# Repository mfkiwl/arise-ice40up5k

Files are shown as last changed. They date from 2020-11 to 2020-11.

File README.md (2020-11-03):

# arise
Low cost development board based on UP5K.
This is an open-source platform based on a low cost FPGA chip from Lattice, aiming to be used in a wide range of signal processing and control applications, both for education and the industry.
This development supports the Open Source toolchain by [Clifford Wolf](http://www.clifford.at/icestorm/).

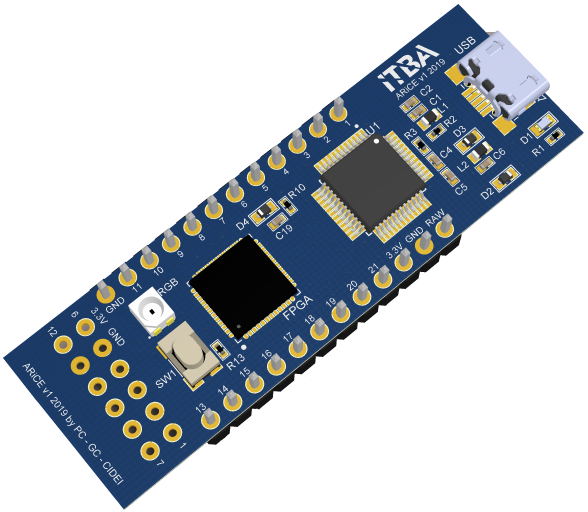
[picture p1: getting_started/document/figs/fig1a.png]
ARiCE


## Getting Started

- If you are starting from scratch, read our [Getting Started Guide](getting_started/document/gs_apio.pdf) to set up the software to program the FPGA board. Further documentation can be found in the ["getting_started" folder](getting_started/document).
- Example code for the recommended software can be found in the ["examples" folder](getting_started/example).
- You can download the Schematics and board files by going to the ["altium" folder](Altium) in this repository or by visiting our project in [Circuit Maker](https://workspace.circuitmaker.com/Projects/Details/Gonzalo-Castelli/FPGA-ITBA), a free PCB design software for the Open Source Hardware community.
- KiCAD version in progress

## Authors
This project was concieved at Instituto Tecnológico de Buenos Aires, in Argentina, by the Industrial Electronic Research and Development Center members:
* **Pablo Cossutta** - *Initial work* - [GitHub page](https://github.com/pcossutta)
* **Gonzalo Castelli** - *Initial work* - [GitHub page](https://github.com/gonzalocastelli)

## License

This project is licensed under a Creative Commons Attribution Share-Alike license, meaning that you are free to use and adapt it for your own needs without asking for permission or paying a fee, even for commercial purposes, as long as you give appropriate credit and release the design under the same license. See the [LICENSE.md](LICENSE.md) file for details, or visit the [Creative Commons Website](https://creativecommons.org/licenses/by-sa/3.0/).

## Acknowledgments

* Circuit was inspired by the official manuals and toolchain of the [iCE40 UltraPlus Breakout Board](http://www.latticesemi.com/en/Products/DevelopmentBoardsAndKits/iCE40UltraPlusBreakoutBoard.aspx) from Lattice, and the documentation of the iCE40UP5K FPGA chip.

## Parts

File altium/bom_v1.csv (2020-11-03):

Designator | Part Number | Qty | Link
C1, C7, C11, C13, C15, C17, C20, C22 | 302010040 | 8 | CC0402KRX5R6BB105 | 1uF 0402
C2, C3, C4, C5, C6, C10, C12, C14, C16, C18, C19, C21, C23 | 302010024 | 13 | CC0402KRX7R8BB104 | 0.1 uF 0402
C8, C9 | 302010139 | 6 | CC0603KRX7R8BB105 | 1uF 0603
R2 | 301010039 | 1 | RC0402JR-072K2L
D1 | 304090045 | 1 | 19-217-BHC-ZL1M2RY-3T
D2, D3, D4 | CDBU0520 | 3
FPGA | ICE40UP5K-SG48I | 1 | https://www.digikey.com/product-detail/en/lattice-semiconductor-corporation/ICE40UP5K-SG48I/220-2212-1-ND/9563352
L1 | HI0603P600R-10 | 1
L2, L3, L4 | BLM18HE601SN1D | 3
MEM | W25Q32JVSSIQ | 1
OSC1 | SIT8924BE-72-XXE-12.000000E | 1
R1 | 301010006 | 1
R3, R4, R5, R6, R7, R13 | 301010047 | 6
R8, R9, R10, R11, R12 | AC0402JR-071RL | 5
RGB | CLMVC-FKA-CL1D1L71BB7C3C3 | 1
SW1 | 311020518 | 1
U1 | FT232HL-REEL | 1
U2 | TLV1117LV33DCYR | 1
U3 | LP5907MFX-1.2/NOPB | 1
USB | 320010000 | 1

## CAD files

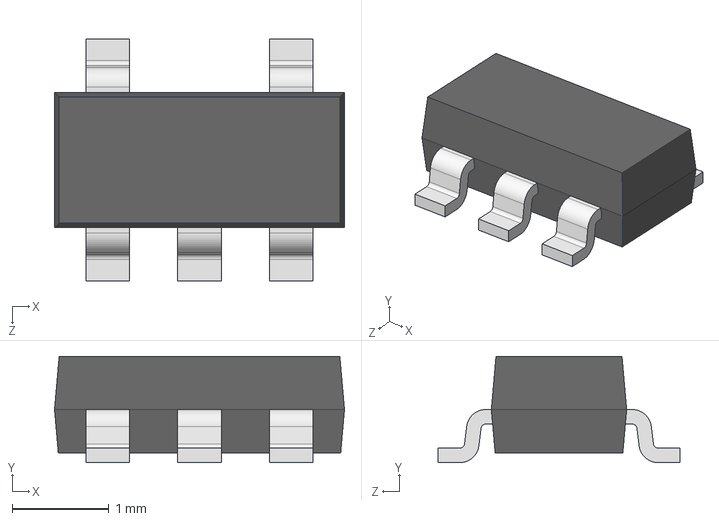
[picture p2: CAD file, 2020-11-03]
altium/3D models/SW3DPS-SOT-23-5-DEFAULT.STEP
3.00 x 1.10 x 2.50 mm

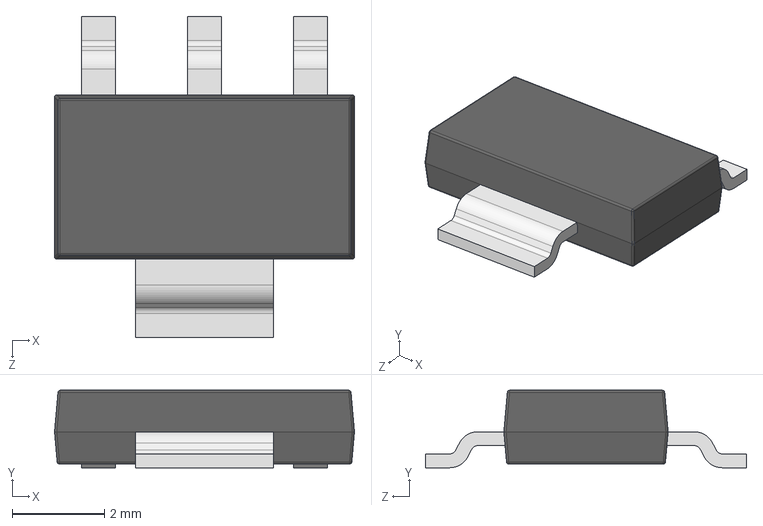
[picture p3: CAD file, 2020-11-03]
altium/My Libraries/Burr-Brown/SW3DPS-SOT-223-DEFAULT.STEP
6.50 x 1.68 x 6.96 mm

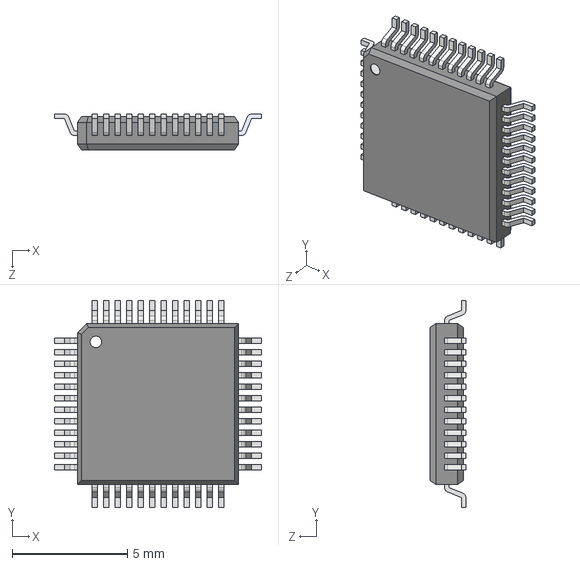
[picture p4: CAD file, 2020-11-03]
altium/My Libraries/Imported FT232HL-REEL.lia/SW3dPS-Quad50M48.STEP
9.00 x 9.00 x 1.56 mm

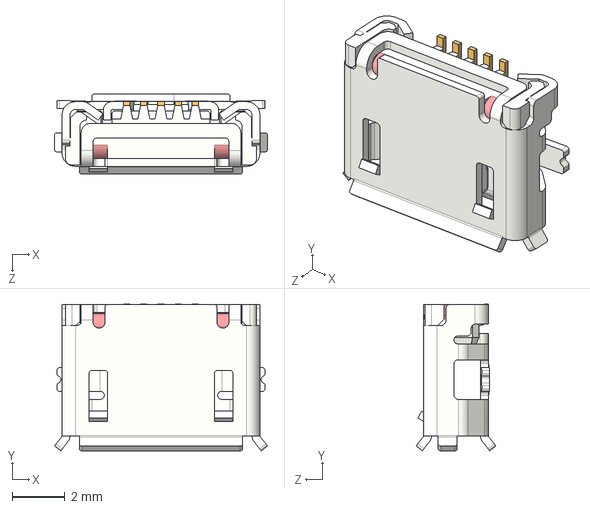
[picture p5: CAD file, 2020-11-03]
altium/My Libraries/Seeed/Connectors/User Library-10104110.STEP
8.08 x 5.56 x 3.03 mm

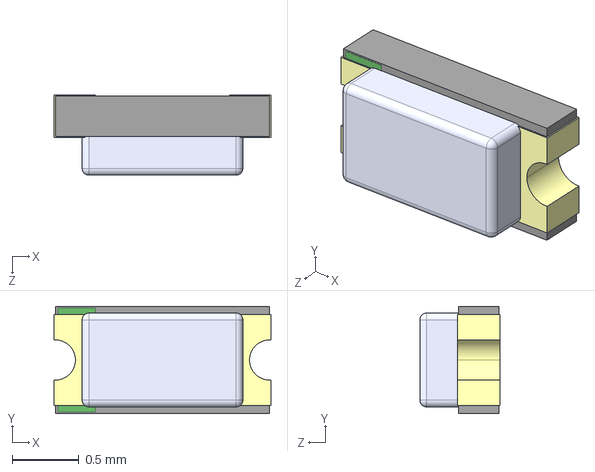
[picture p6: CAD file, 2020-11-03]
altium/My Libraries/Seeed/LED/alsrobot-LED0603(G).STEP
1.62 x 0.8 x 0.6 mm

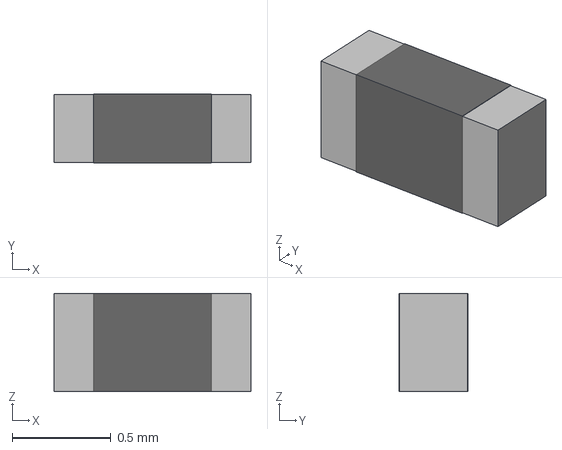
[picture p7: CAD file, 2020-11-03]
altium/My Libraries/Seeed/Resistors/rnd_1550402wgf470ktce.stp
1.00 x 0.35 x 0.5 mm

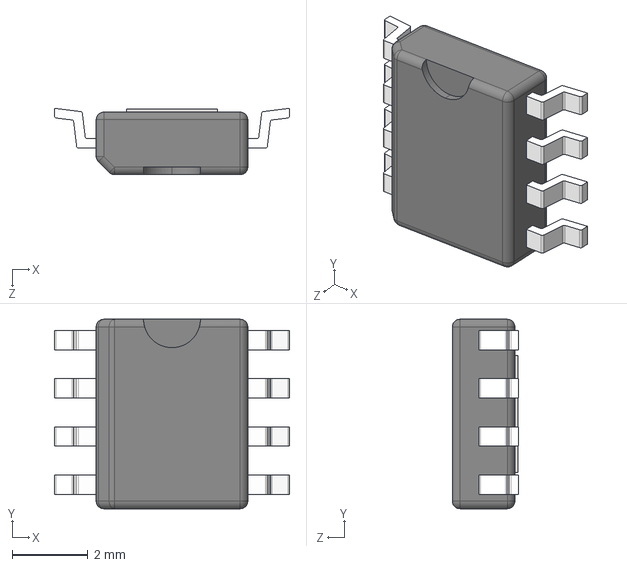
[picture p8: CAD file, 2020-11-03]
altium/3D models/User Library-HSOP8-1.STEP
6.20 x 5.00 x 1.75 mm
User Library-HSOP8-1_SO8
User Library-HSOP8-1_Extruded

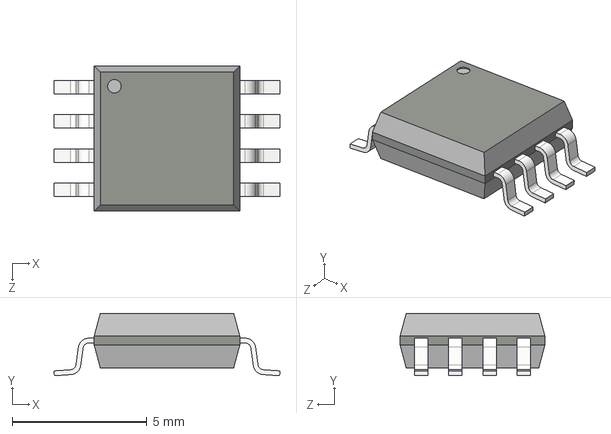
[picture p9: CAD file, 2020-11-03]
altium/3D models/SW3dPS-SOIC8_(ATTINY12).STEP
8.39 x 2.32 x 5.38 mm

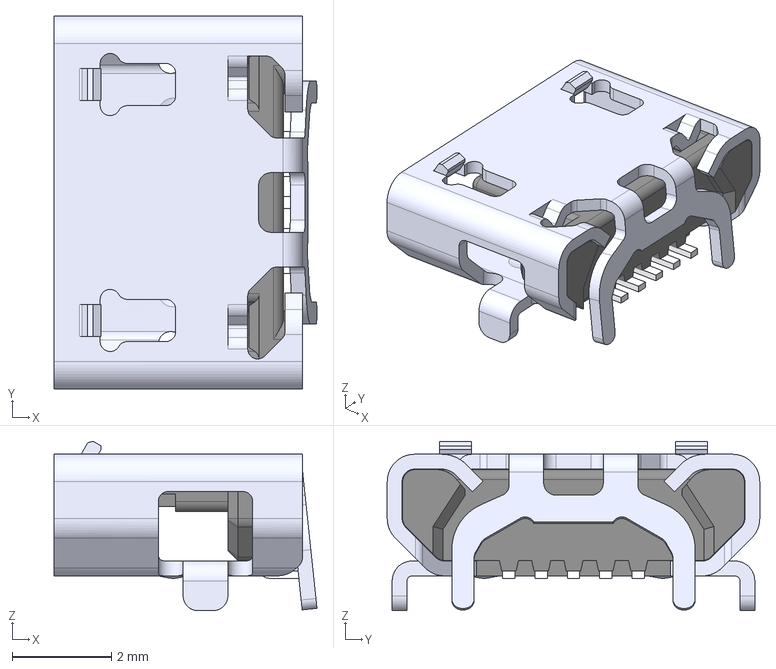
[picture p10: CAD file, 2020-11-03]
altium/3D models/uj2-mibh2-4-smt.stp
5.29 x 7.50 x 3.41 mm

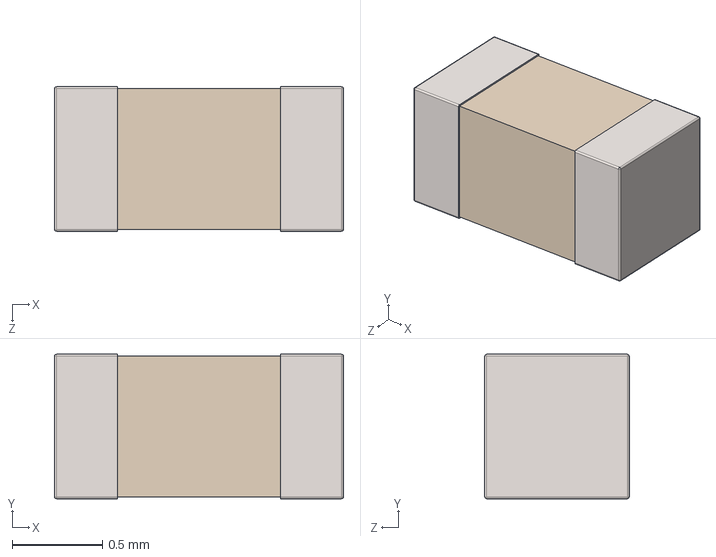
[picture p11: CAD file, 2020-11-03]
altium/3D models/User Library-SMD CAPACITOR0603.STEP
1.60 x 0.8 x 0.8 mm

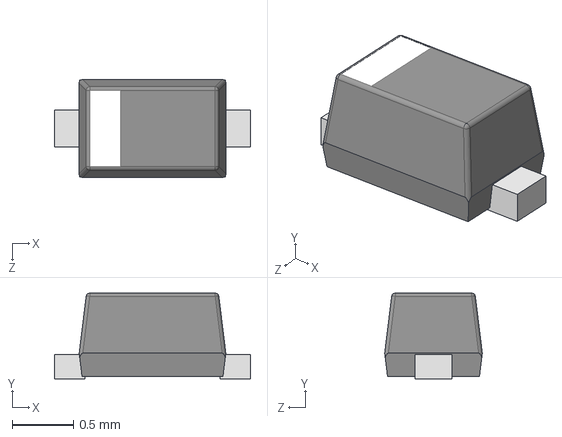
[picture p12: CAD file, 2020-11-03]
altium/3D models/User Library-SOD-523F.STEP
1.60 x 0.7 x 0.798 mm

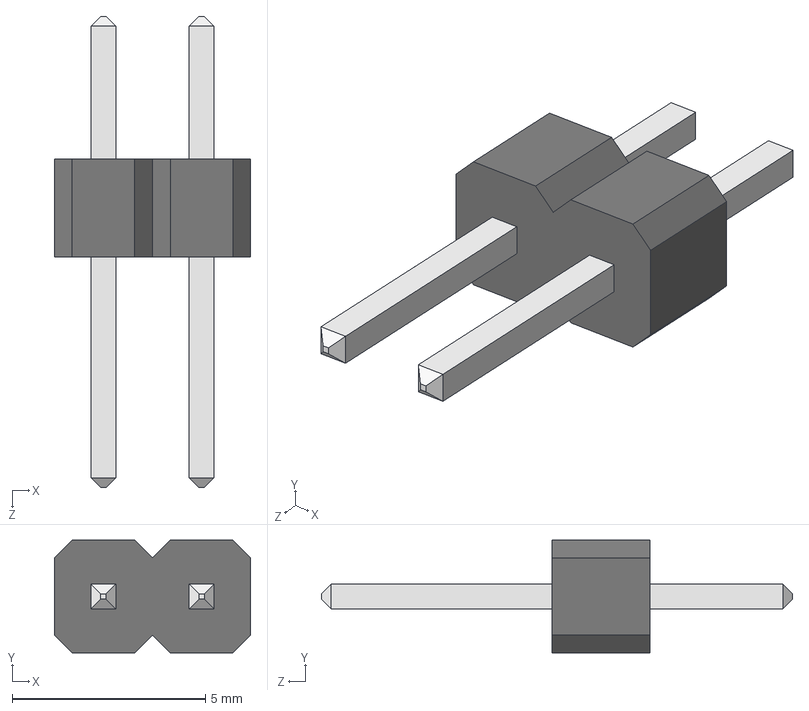
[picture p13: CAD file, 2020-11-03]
altium/3D models/User Library-Pin Header Strip.STEP
5.08 x 2.92 x 12.2 mm

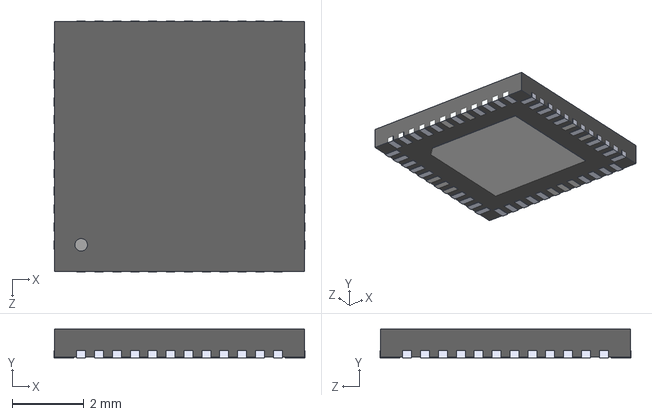
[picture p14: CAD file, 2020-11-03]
altium/3D models/ALSRobot-QFN48 7x7.STEP
7.02 x 0.8 x 7.02 mm

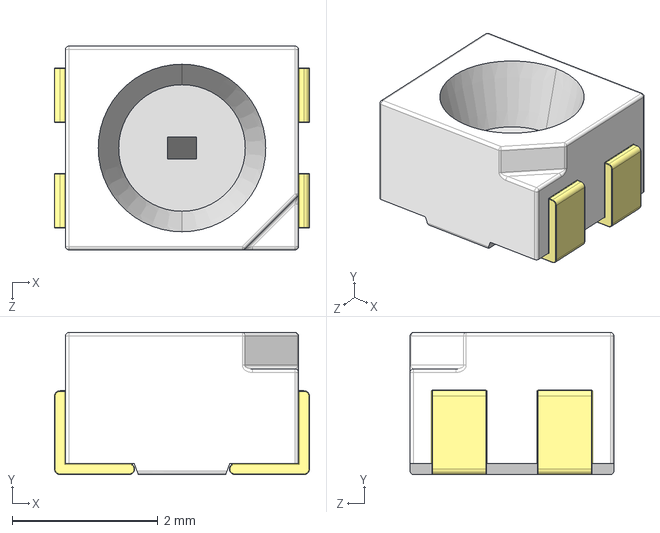
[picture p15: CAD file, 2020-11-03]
altium/3D models/SW3dPS-Osram_Led_PLCC4-1.STEP
3.50 x 1.95 x 2.80 mm

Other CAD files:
altium/3D models/User Library-LS8.STEP
altium/3D models/45631.stp
altium/3D models/User Library-Oscillator2520-4pol.STEP
altium/3D models/User Library-SMD CAPACITOR0402.STEP

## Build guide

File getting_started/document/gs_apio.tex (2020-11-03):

% !TEX encoding = UTF-8 Unicode
\documentclass[11pt, a4paper, oneside]{article}
\usepackage[onehalfspacing]{setspace}		% One half spacing
\usepackage{hyperref}					% Hyperlinks on pdf (Should be called before Geometry)
\usepackage[a4paper, 					% Page Layout
                     %showframe,				% This shows the frame
                     twoside, includehead,
                     footskip=7mm, headsep=6mm, headheight=4.8mm,
                     marginparsep=2mm, marginparwidth=22mm,
                     top=25mm, bottom=25mm, inner=30mm, outer=25mm]{geometry}
\usepackage{sansmathfonts}				% Sans Serif equations
\usepackage[T1]{fontenc}					% Output font encoding for international characters
\usepackage[utf8]{inputenc}				% Encoding of files: utf8
\renewcommand*\familydefault{\sfdefault} 		% Sans Serif as default font
\usepackage[table]{xcolor}
\usepackage{graphicx}
\usepackage{pdfpages}
\usepackage{array}
\hypersetup{
    colorlinks=true,
    linkcolor=blue,
    filecolor=magenta,      
    urlcolor=blue,
}
\urlstyle{same}
\usepackage{tikz}
\RequirePackage{caption} 				% Caption customization
\captionsetup{justification=centerlast,font=small,labelfont=sc,margin=1cm}

\usepackage{array}
\newcommand{\PreserveBackslash}[1]{\let\temp=\\#1\let\\=\temp}
\newcolumntype{C}[1]{>{\PreserveBackslash\centering}p{#1}}
\newcolumntype{R}[1]{>{\PreserveBackslash\raggedleft}p{#1}}
\newcolumntype{L}[1]{>{\PreserveBackslash\raggedright}p{#1}}

\begin{document}
\begin{titlepage}
	\onehalfspacing
	\enlargethispage{0.65\baselineskip}
	\begin{tikzpicture}[remember picture, overlay]
		\coordinate (top_right) at 
		    ([xshift=-2.5cm, yshift=-2.5cm]current page.north east);
		\coordinate (top_left) at 
		    ([xshift=2.3cm, yshift=-1.8cm]current page.north west);
		\coordinate (bottom_right) at 
		    ([xshift=-1.8cm, yshift=1.8cm]current page.south east);
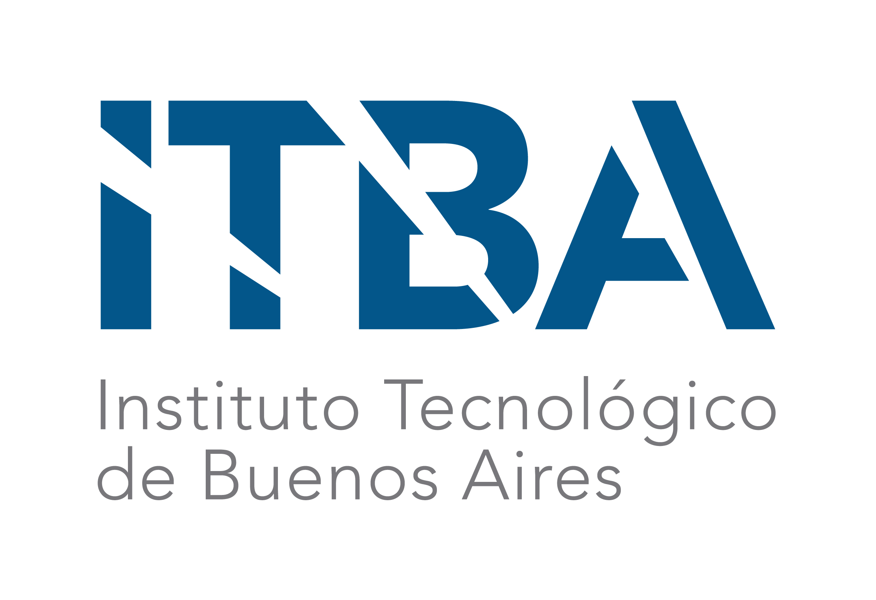
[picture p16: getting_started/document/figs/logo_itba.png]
		\node[inner sep=0, anchor=north east] at (top_right) {\href{http://www.itba.edu.ar}{}};
		\draw[double, line width = 0.5pt] (top_left) rectangle (bottom_right);
	\end{tikzpicture}
	\par
	\vspace{-0.8cm}
	\noindent \textbf{CENTRO DE INVESTIGACIÓN Y DESARROLLO EN}\par
	\noindent \textbf{ELECTRONICA INDUSTRIAL (CIDEI)}\par
	\vspace{3cm}
	\begin{center}
		{\Huge \textbf{ARiCE Plattform}\par}
		{\huge \textbf{Getting Started Apio}\par}
	\end{center}
	\vspace{1cm}
	\begin{center}
		
	\end{center}
	\vfill
	\noindent \textbf{AUTHORS:} Dr. Ing. Pablo \textsc{Cossutta} - Ing. Gonzalo \textsc{Castelli} - Rodrigo \textsc{Devesa} \par
	\vfill
	\begin{center}
		\textbf{CIUDAD AUTÓNOMA DE BUENOS AIRES}\\
		\textbf{2018-2019}\par
	\end{center}
\end{titlepage}

\tableofcontents
\newpage

\section{Introduction}
This project is an open-source platform,shown on Fig. \ref{fig1},  based on a low cost and low consumption FPGA chip from \href{http://www.latticesemi.com}{Lattice Semiconductor}, aiming to be used in a wide range of signal processing and control applications, both for education and the industry.
%
\begin{figure}[h!]
	\centering
	\\
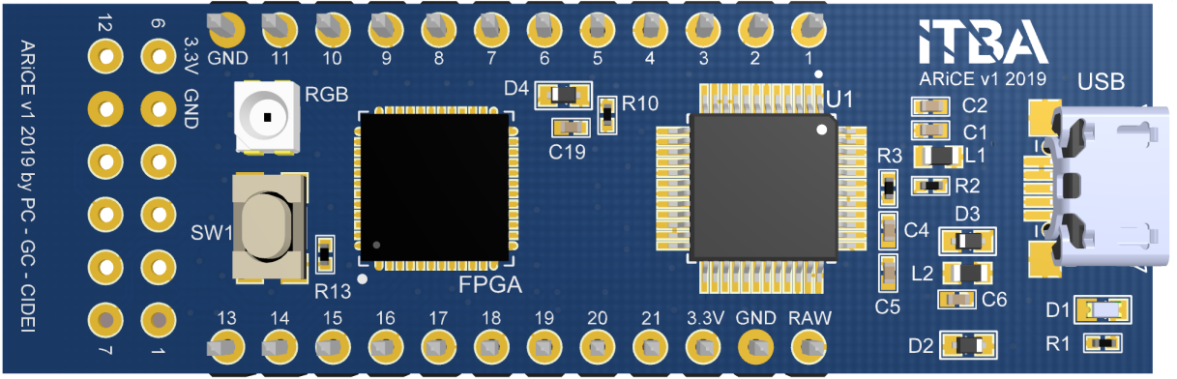
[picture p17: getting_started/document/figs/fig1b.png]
	%
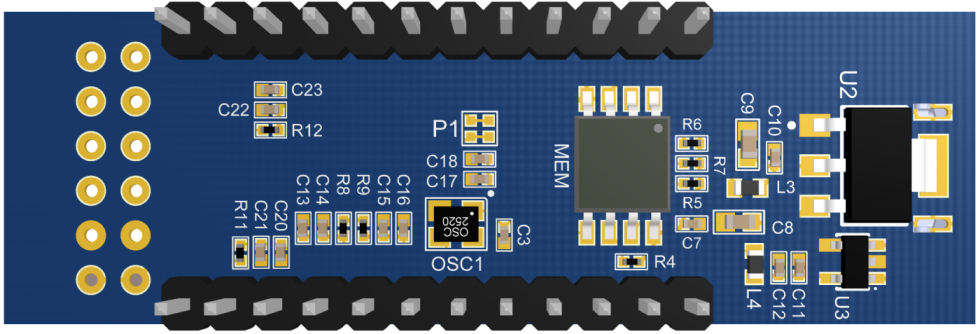
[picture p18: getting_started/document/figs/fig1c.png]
	
	\caption{Board's view}
	\label{fig1}
\end{figure}

%\subsection{Project file sources}
%The following list shows the different file sources for this project:
%\begin{itemize}
%	\item Getting Started Guide and Documentation: \href{https://github.com/pcossutta/Lattice-FPGA/tree/master/Documents/Manuals}{GitHub manuals}
%	\item PCB and Schematics: \href{https://workspace.circuitmaker.com/Projects/Details/Gonzalo-Castelli/FPGA-ITBA}{Circuit Maker} and \href{https://github.com/pcossutta/Lattice-FPGA/tree/master/Altium}{GitHub Altium Project Files}
%	\item \href{https://github.com/pcossutta/Lattice-FPGA/tree/master/Examples/LedExample}{Example code} for the Lattice Radiant software.
%\end{itemize}

\section{Getting started}
Without no previous knowledge, three main steps are necessary to use the board if you are starting from scratch. The first is to download and install the software, the second is to create a new project and include the code files needed and finally load the program to the onboard memory using a USB cable.

\subsection{Downloading the software}
Before using the board, it is necessary to set up the software to program the Lattice iCE40-UP5K FPGA chip. In this tutorial we will be utilizing the  \href{https://apiodoc.readthedocs.io/en/stable/index.html}{Apio Open Source Ecosystem for FPGAs}, which allows to verify the code and program the FPGA through a USB port.\href{https://apiodoc.readthedocs.io/en/stable/index.html}{Python 3.7+} should be previously installed in order to install Apio.

During Python installation, make sure to select "\textbf{Customize Installation}". Then, on the optional features screen, select to install pip, as shown in  Fig. \ref{fig2}, as we will be using it to download the Apio packages.
\ref{fig2}.

\begin{figure}[h!]
    \centering
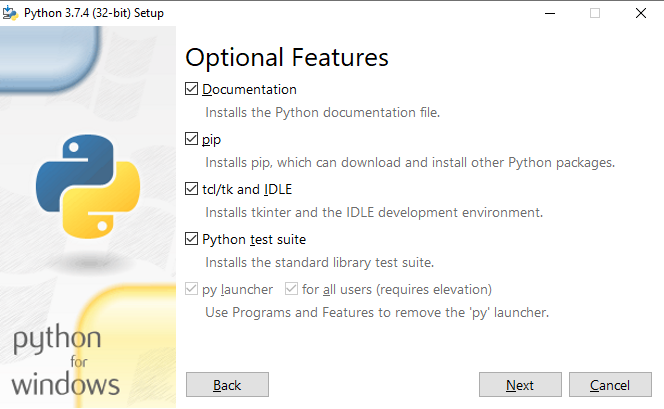
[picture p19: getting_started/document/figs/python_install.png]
    
    \caption{Setting up the Python installation}
    \label{fig2}
\end{figure}

Once Python is successfully installed along with Pip, you can install Apio. On Windows, open your command line console and type:
\begin{center}
	\texttt{pip install -U apio}
\end{center}
When it's finished, you will need to install Apio's packages. Use the following command:
\begin{center}
	\texttt{apio install -{}-all}
\end{center}
This installation might take a few minutes.

\subsection{Creating a new project}
After having installed the software, the next step is to create a new folder for the project and start writing the code. An example code that uses the onboard RGB LED is available for download at the GitHub repository of this project. After downloading the files, place them in an easily accessible folder from where we will run the code.

Use the \texttt{cd} command followed by the path to your project's folder to change directory to that folder. For example, if your project is on a folder called "fpga\_project" in your Desktop, then use:
\begin{center}
	\texttt{cd Desktop/fpga\_project}
\end{center}

Once in the right folder, you need to generate the right .init configuration file for this board, as Apio supports multiple different FPGA platforms. To do this, use the command:

\begin{center}
	\texttt{apio init -{}-board upduino2}
\end{center}

Now, to make sure the project is set up correctly, you could use the command:
\begin{center}
	\texttt{apio build}
\end{center}
The folder should contain at least 3 files, one .v file with the program's code itself, one .pcf file with pinout information for the program, and the .init file we just created. If the build process is successful, you can move on to programming the FPGA board.
 
\subsection{Programming the board}
Now that the project is fully set up, we can load the program into our board to run it.
Connect the FPGA board to the PC using the USB cable, wait a few seconds for Windows to configure the drivers, then use the following command to program the board:
\begin{center}
	\texttt{apio upload}
\end{center}
The process will take a few seconds, and if everything went right, the FPGA board should start running the program and its onboard LED should start flashing in colors.

\subsection{Model simulation}
To simulate the model the following command is used:
\begin{center}
	\texttt{apio sim}
\end{center}

The \href{http://gtkwave.sourceforge.net}{GTKWave} graphic environment should be load with the simulation data.
\input{gs_common.tex}

\end{document}

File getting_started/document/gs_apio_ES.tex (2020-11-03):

% !TEX encoding = UTF-8 Unicode
\documentclass[11pt, a4paper, oneside]{article}
\usepackage[onehalfspacing]{setspace}		% One half spacing
\usepackage{hyperref}					% Hyperlinks on pdf (Should be called before Geometry)
\usepackage[a4paper, 					% Page Layout
                     %showframe,				% This shows the frame
                     twoside, includehead,
                     footskip=7mm, headsep=6mm, headheight=4.8mm,
                     marginparsep=2mm, marginparwidth=22mm,
                     top=25mm, bottom=25mm, inner=30mm, outer=25mm]{geometry}
\usepackage{sansmathfonts}				% Sans Serif equations
\usepackage[T1]{fontenc}					% Output font encoding for international characters
\usepackage[utf8]{inputenc}				% Encoding of files: utf8
\renewcommand*\familydefault{\sfdefault} 		% Sans Serif as default font
%
\usepackage[spanish, es-tabla, es-nodecimaldot]{babel}
\addto\captionsspanish{\renewcommand{\contentsname}{Contenido}}
%
\usepackage[table]{xcolor}
\usepackage{graphicx}
\usepackage{pdfpages}
\usepackage{array}
\hypersetup{
    colorlinks=true,
    linkcolor=blue,
    filecolor=magenta,      
    urlcolor=blue,
}
\urlstyle{same}
\usepackage{tikz}
\RequirePackage{caption} 				% Caption customization
\captionsetup{justification=centerlast,font=small,labelfont=sc,margin=1cm}

\usepackage{array}
\newcommand{\PreserveBackslash}[1]{\let\temp=\\#1\let\\=\temp}
\newcolumntype{C}[1]{>{\PreserveBackslash\centering}p{#1}}
\newcolumntype{R}[1]{>{\PreserveBackslash\raggedleft}p{#1}}
\newcolumntype{L}[1]{>{\PreserveBackslash\raggedright}p{#1}}

\begin{document}
\begin{titlepage}
	\onehalfspacing
	\enlargethispage{0.65\baselineskip}
	\begin{tikzpicture}[remember picture, overlay]
		\coordinate (top_right) at 
		    ([xshift=-2.5cm, yshift=-2.5cm]current page.north east);
		\coordinate (top_left) at 
		    ([xshift=2.3cm, yshift=-1.8cm]current page.north west);
		\coordinate (bottom_right) at 
		    ([xshift=-1.8cm, yshift=1.8cm]current page.south east);
		\node[inner sep=0, anchor=north east] at (top_right) {\href{http://www.itba.edu.ar}{}};
		\draw[double, line width = 0.5pt] (top_left) rectangle (bottom_right);
	\end{tikzpicture}
	\par
	\vspace{-0.8cm}
	\noindent \textbf{CENTRO DE INVESTIGACIÓN Y DESARROLLO EN}\par
	\noindent \textbf{ELECTRONICA INDUSTRIAL (CIDEI)}\par
	\vspace{3cm}
	\begin{center}
		{\Huge \textbf{Plataforma ARiCE}\par}
		{\huge \textbf{Primeros Pasos Apio}\par}
	\end{center}
	\vspace{1cm}
	\begin{center}
		
	\end{center}
	\vfill
	\noindent \textbf{AUTORES:} Dr. Ing. Pablo \textsc{Cossutta} - Ing. Gonzalo \textsc{Castelli} - Rodrigo \textsc{Devesa} \par
	\vfill
	\begin{center}
		\textbf{CIUDAD AUTÓNOMA DE BUENOS AIRES}\\
		\textbf{2018-2019}\par
	\end{center}
\end{titlepage}

\tableofcontents
\newpage

\section{Introducción}
Este proyecto es una plataforma de código abierto, la cual se muestra en la Fig. \ref{fig1}, basado en una placa FPGA de bajo costo y bajo consumo de \href{http://www.latticesemi.com}{Lattice Semiconductor}. Tiene como objetivo ser utilizada en una amplia gama de aplicaciones de procesamiento de señales y control, tanto para la educación como para la industria.
%
\begin{figure}[h!]
	\centering
	\\
	%
	
	\caption{Vistas de la placa}
	\label{fig1}
\end{figure}

%\subsection{Project file sources}
%The following list shows the different file sources for this project:
%\begin{itemize}
%	\item Getting Started Guide and Documentation: \href{https://github.com/pcossutta/Lattice-FPGA/tree/master/Documents/Manuals}{GitHub manuals}
%	\item PCB and Schematics: \href{https://workspace.circuitmaker.com/Projects/Details/Gonzalo-Castelli/FPGA-ITBA}{Circuit Maker} and \href{https://github.com/pcossutta/Lattice-FPGA/tree/master/Altium}{GitHub Altium Project Files}
%	\item \href{https://github.com/pcossutta/Lattice-FPGA/tree/master/Examples/LedExample}{Example code} for the Lattice Radiant software.
%\end{itemize}

\section{Primeros pasos}
Para comenzar a utiliza la plataforma hay que cumplir tres pasos. El primero es descargar e instalar el software, después crear un proyecto incluyendo los archivos de código necesarios y por último cargar el programa en la memoria interna del FPGA usando un cable USB.

\subsection{Descargando el software}
Antes de usar la placa, es necesario descargar el software para programar la FPGA Lattice iCE40-UP5K. En este tutorial se va a utilizar la distribución basada en \href{https://apiodoc.readthedocs.io/en/stable/index.html}{Apio Open Source Ecosystem for FPGAs}, la cual permite sintetizar, implementar y verificar el código y también programar la FPGA mediante un puerto USB. \href{https://apiodoc.readthedocs.io/en/stable/index.html}{Python 3.7+} debe ser instalado previamente para poder instalar Apio.

Durante la instalación de Python debe asegurarse de seleccionar "\textbf{Customize Installation}". Luego, dentro de las opciones adicionales, seleccionar la instalación de \textit{pip},como se muestra en la Fig. \ref{fig2}, dado que se necesita para descargar e instalar el paquete de Apio.

\begin{figure}[h!]
    \centering
    
    \caption{Configuración de la instalación de Python}
    \label{fig2}
\end{figure}

Una vez finalizada la instalación de Python con pip, se procede a instalar Apio. En Windows, se debe abrir una consola de comandos e ingresar:
\begin{center}
	\texttt{pip install -U apio}
\end{center}
Cuando finaliza, es necesario instalar los paquetes adicionales de Apio utilizando el siguiente comando:
\begin{center}
	\texttt{apio install -{}-all}
\end{center}
Esta proceso puede demorar varios minutos.

\subsection{Creando un nuevo proyecto}
Una vez instalado el software, el siguiente paso es crear una nueva carpeta para el proyecto, y empezar as escribir el código. Un ejemplo de proyecto que utiliza el LED RGB montado en la placa esta disponible en nuestro repositorio Github. Después de descargar los archivos, se colocan en una carpeta fácilmente accesible desde donde ejecutaremos el código.

Use el comando \texttt{cd} seguido por la dirección de la carpeta de proyecto para seleccionarla y trabajar sobre ella. Por ejemplo, si el proyecto esta en una carpeta llamada "fpga\_project" en el Escritorio, use:
\begin{center}
	\texttt{cd Desktop/fpga\_project}
\end{center}

Una vez seleccionada la carpeta a utilizar, generamos el archivo de configuración .init adecuado para nuestra placa, ya que Apio soporta varias plataformas de FPGA diferentes. Para hacer esto, use el comando:
\begin{center}
	\texttt{apio init -{}-board upduino2}
\end{center}

Ahora puede usar el comando:
\begin{center}
	\texttt{apio build}
\end{center}
 para asegurar que el proyecto esta correctamente configurado. La carpeta debería contener al menos 3 archivos; un .v con el código del programa, un .pcf con información de entradas y salidas para el programa, y el archivo .init que acabamos de crear. Si el programa compila correctamente, puede pasar a programar la placa FPGA.
 
\subsection{Programando la placa}
Ahora que el proyecto esta armado, podemos cargar el programa a nuestra placa para ejecutarlo.

Conecte la FPGA a la PC con un cable USB, espere unos segundos para que Windows configure los controladores, y luego utilice el siguiente comando para programar la placa:
\begin{center}
	\texttt{apio upload}
\end{center}

El proceso puede demorar algunos segundos. Si todo funcionó correctamente, la placa debería configurarse desde la memoria flash interna y el LED comenzará a prenderse y a cambiar de color.

\subsection{Simulando el diseño}
Para simular el diseño ejecutar el siguiente comando:
\begin{center}
	\texttt{apio sim}
\end{center}

Se cargará el visualizador \href{http://gtkwave.sourceforge.net}{GTKWave} y se podrá analizar el resultado de la simulación.

\input{gs_common_ES.tex}
\end{document}

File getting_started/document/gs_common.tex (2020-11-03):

% !TEX encoding = UTF-8 Unicode
\newpage
\section{Pinout information}
The board has multiple I/O pins, as well as power supply pins, distributed along the side and the front of the PCB. The next list gives a short description of the signals:
\begin{itemize}
	\item IOT\_XX are general I/O pins. In user mode, after configuration, these pins can be programmed as I/O in user function in the top (xx = I/O location)
	\item IOB\_XX are general I/O pins. In user mode, after configuration, these pins can be programmed as I/O in user function in the bottom (xx = I/O location)
	\item RAW VCC. The input voltage to the FPGA board when it's using an external power source. The board can be supplied with power either from the USB connector or the RAW VCC pin. The nominal supply voltage is 5V. (Minimum is 4.5V and maximum is 6V)
	\item 3.3V. A 3.3 volt supply generated by the on-board regulator. Maximum recommended current draw from this pin is 500 mA
	\item GND. Ground pins
	\item Signal names with G1, G3 and G6 suffixes may be used as a General I/O or as a Global input used for high fanout, or clock/reset net. These pins drive the GBUF1, GBUF3 and GBUF6 global buffers respectively
\end{itemize}

\newpage
Table \ref{table1} shows the mapping between the signals and the board pin numbers.
\definecolor{myHdr}{rgb}{0.81000,0.8800,0.9400}%
\begin{table}[h!]
	\renewcommand{\arraystretch}{1.3}
	\caption{Connections}
	\label{table1}
	\begin{tabular}[t]{C{0.12\textwidth} C{0.12\textwidth} C{0.15\textwidth}}
		\bfseries Board Pin & \bfseries FPGA Pin & \bfseries Signal Name \\ \hline
		\rowcolor{myHdr} \multicolumn{3}{c}{\bfseries Side Pins} \\ \hline
		1 & 20 & IOB 25B G3 \\
		2 & 21 & IOB 23B \\
		3 & 23 & IOT 37A \\
		4 & 25 & IOT 36B \\
		5 & 26 & IOT 39A \\
		6 & 27 & IOT 38B \\
		7 & 31 & IOT 42B \\
		8 & 32 & IOT 43A \\
		9 & 34 & IOT 44B \\
		10 & 36 & IOT 48B \\
		11 & 37 & IOT 45A G1 \\
		12 & - & GND \\
		& & \\
		13 & 2 & IOB 6A \\
		14 & 6 & IOB 13B \\
		15 & 9 & IOB 16A \\
		16 & 10 & IOB 18A \\
		17 & 11 & IOB 20A \\
		18 & 12 & IOB 22A \\
		19 & 13 & IOB 24A \\
		20 & 18 & IOB 31B \\
		21 & 19 & IOB 29B \\
		22 & - & 3.3V \\
		23 & - & GND \\
		24 & - & RAW VCC \\
	\end{tabular}
	\quad
	\begin{tabular}[t]{C{0.12\textwidth} C{0.12\textwidth} C{0.15\textwidth}}
		\bfseries Board Pin & \bfseries FPGA Pin & \bfseries Signal Name \\ \hline
		\rowcolor{myHdr} \multicolumn{3}{c}{\bfseries Front Pins} \\ \hline
		1 & 4 & IOB 8A \\
		2 & 3 & IOB 9B \\
		3 & 47 & IOB 2A \\
		4 & 44 & IOB 3B G6 \\
		5 & - & GND \\
		6 & - & 3.3V \\
		7 & 48 & IOB 4A \\
		8 & 45 & IOB 5B \\
		9 & 38 & IOT 50B \\
		10 & 42 & IOT 51A \\
		11 & - & GND \\
		12 & - & 3.3V \\
		& & \\
		\bfseries Board Pin & \bfseries FPGA Pin & \bfseries Signal Name \\ \hline
		\rowcolor{myHdr} \multicolumn{3}{c}{\bfseries Not Connected} \\ \hline
		 - & 43 & IOT 49A \\
		- & 46 & IOB 0A \\
		- & 28 & IOT 41A \\	
		& & \\
		& & \\
		\bfseries LED Color & \bfseries FPGA Pin & \bfseries Signal Name \\ \hline
		\rowcolor{myHdr} \multicolumn{3}{c}{\bfseries Onboard RGB LED} \\   \hline
		Blue & 39 & RGB0 \\
		Green & 40 & RGB1 \\
		Red & 41 & RGB2 \\
	\end{tabular}
\end{table}

\newpage
The differential pairs are shown in Table \ref{table2}. They are grouped together and labeled in colors, white is positive and light blue is negative.
%
\begin{table}[h!]
	\renewcommand{\arraystretch}{1.3}
	\caption{Differential Pairs}
	\vspace{0.5em}
	\label{table2}
	\centering
	\begin{tabular}{C{0.12\textwidth} C{0.12\textwidth} C{0.15\textwidth}}
		\bfseries Board Pin & \bfseries FPGA Pin & \bfseries Signal Name \\ \hline
		\rowcolor{myHdr}  3 & 23 & IOT 37A \\
		4 & 25 & IOT 36B \\ \hline
		\rowcolor{myHdr}  5 & 26 & IOT 39A \\
		6 & 27 & IOT 38B \\ \hline
		\rowcolor{myHdr}  8 & 32 & IOT 43A \\
		7 & 31 & IOT 42B \\ \hline
		\rowcolor{myHdr}  11 & 37 & IOT 45A G1 \\
		9 & 34 & IOT 44B \\ \hline
		\rowcolor{myHdr}  2 & 21 & IOB 23B \\
		18 & 12 & IOB 22A \\ \hline
		\rowcolor{myHdr}  2 & 3 & IOB 9B \\
		1 & 4 & IOB 8A \\ \hline
		\rowcolor{myHdr}  4 & 44 & IOB 3B G6 \\
		3 & 47 & IOB 2A \\ \hline
		\rowcolor{myHdr}  8 & 45 & IOB 5B \\ 
		7 & 48 & IOB 4A \\ \hline
		\rowcolor{myHdr}  10 & 42 & IOT 51A \\ 
		9 & 38 & IOT 50B \\
	\end{tabular}
\end{table}

\section{Open Source PCB}
The board files, circuit schematics and list of components are available in the GitHub repository. Altium project and Gerber files are available. The board is also published in open source EDAs just as \href{https://workspace.circuitmaker.com/}{Circuit Maker} and \href{http://www.kicad-pcb.org}{KiCad}.

\newpage
\subsection{Bill of Materials}
Table \ref{table3} includes all the components in the FPGA Board. Follow the hypertext links to the component's datasheets for further information.
%
\begin{table}[h]
	\renewcommand{\arraystretch}{1.3}
	\caption{Bill of materials}
	\vspace{0.5em}
	\label{table3}
	\centering
	\begin{tabular}{p{4cm} C{0.5cm} c C{1cm} p{2cm}}
		\bfseries Designator & \bfseries Qty & \bfseries Manufacturer Part Number & \bfseries Value & \bfseries Footprint \\ \hline
		C2, C3, C4, C5, C6, C10, C12, C14, C16, C18, C19, C21, C23 & 13 & \href{http://www.samsungsem.com/kr/support/product-search/mlcc/CL05B104KA5NNNC.jsp}{CL05B104KA5NNNC} & 0.1uF & 0402 \\ \hline
		C8, C9 & 2 & \href{http://www.yageo.com/documents/recent/UPY-GPHC_X5R_4V-to-50V_25.pdf}{CC0603KRX5R8BB105} & 1uF & 0603 \\ \hline
		C1, C7, C11, C13, C15, C17, C20, C22 & 8 & \href{https://product.tdk.com/info/en/catalog/datasheets/mlcc_commercial_lowprofile_en.pdf}{CGB2A1JB1E105M033BC} & 1uF & 0402 \\ \hline
		R1 & 1 & \href{http://www.yageo.com/documents/recent/PYu-RC_Group_51_RoHS_L_9.pdf}{RC0402JR-071KL} & 1K$\Omega$ & 0402 \\ \hline
		R2 & 1x& \href{http://www.yageo.com/documents/recent/PYu-RC_Group_51_RoHS_L_9.pdf}{RC0402FR-072K2L} & 2.2k$\Omega$ & 0402 \\ \hline
		R3, R4, R5, R6, R7, R13 & 6 & \href{http://www.yageo.com/NewPortal/yageodocoutput?fileName=/pdf/R-Chip/PYu-RC_51_RoHS_P_0.pdf}{RC0402JR-0710KP} & 10k$\Omega$ & 0402 \\ \hline
		R8, R9, R10, R11, R12 & 5 & \href{http://www.yageo.com/NewPortal/yageodocoutput?fileName=/pdf/R-Chip/PYu-AC_51_RoHS_L_6.pdf}{AC0402JR-071RL} & 1$\Omega$ & 0402 \\ \hline
		L1 & 1 & \href{http://assets.lairdtech.com/home/brandworld/files/HI0603P600R-10.pdf}{HI0603P600R-10} & 10mH & 0603 \\ \hline
		L2, L3, L4 & 3 & \href{https://www.murata.com/en-us/products/productdata/8796741599262/ENFA0004.pdf}{BLM18HE601SN1D} & 10mH & 0603 \\ \hline
		RGB & 1 & \href{https://www.cree.com/led-components/media/documents/1273-CLMVC-FKA.pdf}{CLMVC-FKA-CL1D1L71BB7C3C3} & & 4-PLCC \\ \hline
		D1 & 1 & \href{http://optoelectronics.liteon.com/upload/download/DS-22-99-0224/LTST-C190TBKT.PDF}{LTST-C190TBKT} & & 0603 \\ \hline
		U1 & 1 & \href{http://www.ftdichip.com/Support/Documents/DataSheets/ICs/DS_FT232H.pdf}{FT232HL-REEL} & & 48-LQFP (7x7) \\ \hline    
		U2 & 1 & \href{http://www.ti.com/lit/ds/symlink/tlv1117lv.pdf}{TLV1117LV33DCYR} & & SOT-223-4 \\ \hline
		U3 & 1 & \href{http://www.ti.com/lit/ds/symlink/lp5907.pdf}{LP5907MFX-1.2/NOPB} & & SOT-23-5 \\ \hline
		OSC1 & 1 & \href{https://media.digikey.com/pdf/Data\%20Sheets/SiTime\%20PDFs/SIT1602A.pdf}{SIT1602AC-73-33S-12.000000G} & & 2.0X1-6MM \\ \hline
		FPGA & 1 & \href{http://www.latticesemi.com/view_document?document_id=51968}{ICE40UP5K-SG48ITR50} & & 48-QFN-7X7 \\ \hline
		USB & 1 & \href{http://www.amphenol-icc.com/media/wysiwyg/files/drawing/10118193.pdf}{10118193-0001LF} & & Micro USB B SMD \\ \hline
		MEM & 1 & \href{https://www.winbond.com/resource-files/w25q32jv%20dtr%20revf%2002242017.pdf}{W25Q32JVSSIQ} & & SOP8 \\ \hline
		D2, D3, D4 & 3 & \href{http://www.comchiptech.com/admin/files/product/CDBU0520-HF-RevA797161.pdf}{CDBU0520} & & 0603/SOD-523F \\ \hline
		SW1 & 1 & \href{https://www.ckswitches.com/media/1465/kxt3.pdf}{PTS810 SJM 250 SMTR LFS} & & SW4-SMD \\
	\end{tabular}
\end{table}

\subsection{Schematics}
\includepdf[landscape=true]{figs/ftdi.pdf}
\includepdf[landscape=true]{figs/misc.pdf}
\includepdf[landscape=true]{figs/fpga.pdf}

\section{License}
This project is licensed under a Creative Commons Attribution Share-Alike license, meaning that you are free to use and adapt it for your own needs without asking for permission or paying a fee, even for commercial purposes, as long as you give appropriate credit and release the design under the same license. Visit the
\href{https://creativecommons.org/licenses/by-sa/3.0/}{Creative Commons Website} for further information.

\section{Acknowledgments}
The circuit was inspired by the official manuals and toolchain of the \href{http://www.latticesemi.com/en/Products/DevelopmentBoardsAndKits/iCE40UltraPlusBreakoutBoard.aspx}{iCE40 UltraPlus Breakout Board} from Lattice, and the documentation of the iCE40UP5K FPGA chip.

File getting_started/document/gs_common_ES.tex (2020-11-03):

% !TEX encoding = UTF-8 Unicode
\newpage
\section{Información de las conexiones}
La placa posee múltiples pines de E/S, junto con alimentaciones, distribuidas en los conectores laterales y frontales del circuito impreso. La siguiente lista provee una breve descripción de estas señales:
\begin{itemize}
	\item IOT\_XX corresponde a pines estándar de E/S. En el modo usuario, después de la configuración, estos pines pueden ser utilizados como E/S según el usuario y corresponden al banco superior (top, donde xx = ubicación de E/S)
	\item IOB\_XX corresponde a pines estándar de E/S. En el modo usuario, después de la configuración, estos pines pueden ser utilizados como E/S según el usuario y corresponden al banco inferior (bottom, donde xx = ubicación de E/S
	\item RAW VCC. La alimentación de la placa cuando utiliza una fuente de alimentación externa. La alimentación puede provenir tanto del conector USB como del pin RAW VCC (Tensión mínima de 4.5V y máxima de 6V)
	\item 3.3V. Salida de 3.3V generada por el regulador de tensión lineal interno. No excede los 500mA
	\item GND. Pines de referencia
	\item Las señales que contienen los sufijos G1, G3 y G6 pueden ser utilizadas tamos como pines estándar de E/S o señales globales con gran cantidad de conexiones internas o cómo líneas de clock o reset. Estos pines se encuentran conectados a los buffers globales GBUF1, GBUF3 y GBUF6 respectivamente.
\end{itemize}

\newpage
La Tabla \ref{table1} muestra la correspondencia entre la asignación de pines, el nombre de las señales y el pad correspondiente al encapsulado de la FPGA.
\definecolor{myHdr}{rgb}{0.81000,0.8800,0.9400}%
\begin{table}[h!]
	\renewcommand{\arraystretch}{1.3}
	\caption{Conexiones}
	\label{table1}
	\begin{tabular}[t]{C{0.12\textwidth} C{0.12\textwidth} C{0.15\textwidth}}
		\bfseries Pin Placa & \bfseries Pin FPGA & \bfseries Señal \\ \hline
		\rowcolor{myHdr} \multicolumn{3}{c}{\bfseries Conexiones Laterales} \\ \hline
		1 & 20 & IOB 25B G3 \\
		2 & 21 & IOB 23B \\
		3 & 23 & IOT 37A \\
		4 & 25 & IOT 36B \\
		5 & 26 & IOT 39A \\
		6 & 27 & IOT 38B \\
		7 & 31 & IOT 42B \\
		8 & 32 & IOT 43A \\
		9 & 34 & IOT 44B \\
		10 & 36 & IOT 48B \\
		11 & 37 & IOT 45A G1 \\
		12 & - & GND \\
		& & \\
		13 & 2 & IOB 6A \\
		14 & 6 & IOB 13B \\
		15 & 9 & IOB 16A \\
		16 & 10 & IOB 18A \\
		17 & 11 & IOB 20A \\
		18 & 12 & IOB 22A \\
		19 & 13 & IOB 24A \\
		20 & 18 & IOB 31B \\
		21 & 19 & IOB 29B \\
		22 & - & 3.3V \\
		23 & - & GND \\
		24 & - & RAW VCC \\
	\end{tabular}
	\quad
	\begin{tabular}[t]{C{0.12\textwidth} C{0.12\textwidth} C{0.15\textwidth}}
		\bfseries Pin Placa & \bfseries Pin FPGA & \bfseries Señal \\ \hline
		\rowcolor{myHdr} \multicolumn{3}{c}{\bfseries Conexiones Frontales} \\ \hline
		1 & 4 & IOB 8A \\
		2 & 3 & IOB 9B \\
		3 & 47 & IOB 2A \\
		4 & 44 & IOB 3B G6 \\
		5 & - & GND \\
		6 & - & 3.3V \\
		7 & 48 & IOB 4A \\
		8 & 45 & IOB 5B \\
		9 & 38 & IOT 50B \\
		10 & 42 & IOT 51A \\
		11 & - & GND \\
		12 & - & 3.3V \\
		& & \\
		\bfseries Pin Placa & \bfseries Pin FPGA & \bfseries Señal \\ \hline
		\rowcolor{myHdr} \multicolumn{3}{c}{\bfseries No Conectados} \\ \hline
		 - & 43 & IOT 49A \\
		- & 46 & IOB 0A \\
		- & 28 & IOT 41A \\	
		& & \\
		& & \\
		\bfseries Color LED & \bfseries Pin FPGA & \bfseries Señal \\ \hline
		\rowcolor{myHdr} \multicolumn{3}{c}{\bfseries LED RGB interno} \\   \hline
		Azul & 39 & RGB0 \\
		Verde & 40 & RGB1 \\
		Rojo & 41 & RGB2 \\
	\end{tabular}
\end{table}

\newpage
Los pares diferenciales se muestran en la Tabla \ref{table2}. Los mismos están agrupados y en colores, dónde fondo blanco corresponde al terminal positivo y celeste al negativo.
%
\begin{table}[h!]
	\renewcommand{\arraystretch}{1.3}
	\caption{Pares Diferenciales}
	\vspace{0.5em}
	\label{table2}
	\centering
	\begin{tabular}{C{0.12\textwidth} C{0.12\textwidth} C{0.15\textwidth}}
		\bfseries Pin Placa & \bfseries Pin FPGA & \bfseries Señal \\ \hline
		\rowcolor{myHdr}  3 & 23 & IOT 37A \\
		4 & 25 & IOT 36B \\ \hline
		\rowcolor{myHdr}  5 & 26 & IOT 39A \\
		6 & 27 & IOT 38B \\ \hline
		\rowcolor{myHdr}  8 & 32 & IOT 43A \\
		7 & 31 & IOT 42B \\ \hline
		\rowcolor{myHdr}  11 & 37 & IOT 45A G1 \\
		9 & 34 & IOT 44B \\ \hline
		\rowcolor{myHdr}  2 & 21 & IOB 23B \\
		18 & 12 & IOB 22A \\ \hline
		\rowcolor{myHdr}  2 & 3 & IOB 9B \\
		1 & 4 & IOB 8A \\ \hline
		\rowcolor{myHdr}  4 & 44 & IOB 3B G6 \\
		3 & 47 & IOB 2A \\ \hline
		\rowcolor{myHdr}  8 & 45 & IOB 5B \\ 
		7 & 48 & IOB 4A \\ \hline
		\rowcolor{myHdr}  10 & 42 & IOT 51A \\ 
		9 & 38 & IOT 50B \\
	\end{tabular}
\end{table}

\section{Circuito Impreso Libre}
los archivos de diseño, diagramas esquemáticos y el listado de componentes se encuentran disponibles en el repositorio de GitHub. Los archivos del proyecto realizado en Altium y los Gerbers de fabricación están disponibles. Además el diseño está publicado utilizando herramientas libres como \href{https://workspace.circuitmaker.com/}{Circuit Maker} y \href{http://www.kicad-pcb.org}{KiCad}.

\newpage
\subsection{Listado de componentes}
En la Tabla \ref{table3} se incluye todos los componentes de la plataforma ARiCE. Para mayor información se incluye el link con la mayoría de las hojas de datos de los componentes utilizados.
%
\begin{table}[h]
	\renewcommand{\arraystretch}{1.3}
	\caption{Listado de componentes}
	\vspace{0.5em}
	\label{table3}
	\centering
	\begin{tabular}{p{4cm} C{0.5cm} c C{1cm} p{2cm}}
		\bfseries Nombre & \bfseries Cant. & \bfseries Código del Fabricante & \bfseries Valor & \bfseries Footprint \\ \hline
		C2, C3, C4, C5, C6, C10, C12, C14, C16, C18, C19, C21, C23 & 13 & \href{http://www.samsungsem.com/kr/support/product-search/mlcc/CL05B104KA5NNNC.jsp}{CL05B104KA5NNNC} & 0.1uF & 0402 \\ \hline
		C8, C9 & 2 & \href{http://www.yageo.com/documents/recent/UPY-GPHC_X5R_4V-to-50V_25.pdf}{CC0603KRX5R8BB105} & 1uF & 0603 \\ \hline
		C1, C7, C11, C13, C15, C17, C20, C22 & 8 & \href{https://product.tdk.com/info/en/catalog/datasheets/mlcc_commercial_lowprofile_en.pdf}{CGB2A1JB1E105M033BC} & 1uF & 0402 \\ \hline
		R1 & 1 & \href{http://www.yageo.com/documents/recent/PYu-RC_Group_51_RoHS_L_9.pdf}{RC0402JR-071KL} & 1K$\Omega$ & 0402 \\ \hline
		R2 & 1x& \href{http://www.yageo.com/documents/recent/PYu-RC_Group_51_RoHS_L_9.pdf}{RC0402FR-072K2L} & 2.2k$\Omega$ & 0402 \\ \hline
		R3, R4, R5, R6, R7, R13 & 6 & \href{http://www.yageo.com/NewPortal/yageodocoutput?fileName=/pdf/R-Chip/PYu-RC_51_RoHS_P_0.pdf}{RC0402JR-0710KP} & 10k$\Omega$ & 0402 \\ \hline
		R8, R9, R10, R11, R12 & 5 & \href{http://www.yageo.com/NewPortal/yageodocoutput?fileName=/pdf/R-Chip/PYu-AC_51_RoHS_L_6.pdf}{AC0402JR-071RL} & 1$\Omega$ & 0402 \\ \hline
		L1 & 1 & \href{http://assets.lairdtech.com/home/brandworld/files/HI0603P600R-10.pdf}{HI0603P600R-10} & 10mH & 0603 \\ \hline
		L2, L3, L4 & 3 & \href{https://www.murata.com/en-us/products/productdata/8796741599262/ENFA0004.pdf}{BLM18HE601SN1D} & 10mH & 0603 \\ \hline
		RGB & 1 & \href{https://www.cree.com/led-components/media/documents/1273-CLMVC-FKA.pdf}{CLMVC-FKA-CL1D1L71BB7C3C3} & & 4-PLCC \\ \hline
		D1 & 1 & \href{http://optoelectronics.liteon.com/upload/download/DS-22-99-0224/LTST-C190TBKT.PDF}{LTST-C190TBKT} & & 0603 \\ \hline
		U1 & 1 & \href{http://www.ftdichip.com/Support/Documents/DataSheets/ICs/DS_FT232H.pdf}{FT232HL-REEL} & & 48-LQFP (7x7) \\ \hline    
		U2 & 1 & \href{http://www.ti.com/lit/ds/symlink/tlv1117lv.pdf}{TLV1117LV33DCYR} & & SOT-223-4 \\ \hline
		U3 & 1 & \href{http://www.ti.com/lit/ds/symlink/lp5907.pdf}{LP5907MFX-1.2/NOPB} & & SOT-23-5 \\ \hline
		OSC1 & 1 & \href{https://media.digikey.com/pdf/Data\%20Sheets/SiTime\%20PDFs/SIT1602A.pdf}{SIT1602AC-73-33S-12.000000G} & & 2.0X1-6MM \\ \hline
		FPGA & 1 & \href{http://www.latticesemi.com/view_document?document_id=51968}{ICE40UP5K-SG48ITR50} & & 48-QFN-7X7 \\ \hline
		USB & 1 & \href{http://www.amphenol-icc.com/media/wysiwyg/files/drawing/10118193.pdf}{10118193-0001LF} & & Micro USB B SMD \\ \hline
		MEM & 1 & \href{https://www.winbond.com/resource-files/w25q32jv%20dtr%20revf%2002242017.pdf}{W25Q32JVSSIQ} & & SOP8 \\ \hline
		D2, D3, D4 & 3 & \href{http://www.comchiptech.com/admin/files/product/CDBU0520-HF-RevA797161.pdf}{CDBU0520} & & 0603/SOD-523F \\ \hline
		SW1 & 1 & \href{https://www.ckswitches.com/media/1465/kxt3.pdf}{PTS810 SJM 250 SMTR LFS} & & SW4-SMD \\
	\end{tabular}
\end{table}

\subsection{Diagramas esquemáticos}
\includepdf[landscape=true]{figs/ftdi.pdf}
\includepdf[landscape=true]{figs/misc.pdf}
\includepdf[landscape=true]{figs/fpga.pdf}

\section{Licencia}
Este proyecto se provee bajo la licencia \textit{Creative Commons Attribution Share-Alike}, lo que significa que puede ser utilizado libremente, adaptado a sus necesidades, sin necesidad de solicitar o pagar un permiso, siempre y cuando se denote apropiadamente los créditos del creador original y se libere el diseño bajo la misma licencia. Para mayor información visitar el sitio web \href{https://creativecommons.org/licenses/by-sa/3.0/}{Creative Commons}.

\section{Agradecimientos}
Este proyecto se inspira y basa en los manuales oficiales y las herramientas detalladas en \href{http://www.latticesemi.com/en/Products/DevelopmentBoardsAndKits/iCE40UltraPlusBreakoutBoard.aspx}{iCE40 UltraPlus Breakout Board} de Lattice Semiconductors y en la documentación de la FPGA, iCE40UP5K.

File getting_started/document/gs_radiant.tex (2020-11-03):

% !TEX encoding = UTF-8 Unicode
\documentclass[11pt, a4paper, oneside]{article}
\usepackage[onehalfspacing]{setspace}		% One half spacing
\usepackage{hyperref}					% Hyperlinks on pdf (Should be called before Geometry)
\usepackage[a4paper, 					% Page Layout
                     %showframe,				% This shows the frame
                     twoside, includehead,
                     footskip=7mm, headsep=6mm, headheight=4.8mm,
                     marginparsep=2mm, marginparwidth=22mm,
                     top=25mm, bottom=25mm, inner=30mm, outer=25mm]{geometry}
\usepackage{sansmathfonts}				% Sans Serif equations
\usepackage[T1]{fontenc}					% Output font encoding for international characters
\usepackage[utf8]{inputenc}				% Encoding of files: utf8
\renewcommand*\familydefault{\sfdefault} 		% Sans Serif as default font
\usepackage[table]{xcolor}
\usepackage{graphicx}
\usepackage{pdfpages}
\usepackage{array}
\hypersetup{
    colorlinks=true,
    linkcolor=blue,
    filecolor=magenta,      
    urlcolor=blue,
}
\urlstyle{same}
\usepackage{tikz}
\RequirePackage{caption} 				% Caption customization
\captionsetup{justification=centerlast,font=small,labelfont=sc,margin=1cm}

\usepackage{array}
\newcommand{\PreserveBackslash}[1]{\let\temp=\\#1\let\\=\temp}
\newcolumntype{C}[1]{>{\PreserveBackslash\centering}p{#1}}
\newcolumntype{R}[1]{>{\PreserveBackslash\raggedleft}p{#1}}
\newcolumntype{L}[1]{>{\PreserveBackslash\raggedright}p{#1}}

\begin{document}
\begin{titlepage}
	\onehalfspacing
	\enlargethispage{0.65\baselineskip}
	\begin{tikzpicture}[remember picture, overlay]
		\coordinate (top_right) at 
		    ([xshift=-2.5cm, yshift=-2.5cm]current page.north east);
		\coordinate (top_left) at 
		    ([xshift=2.3cm, yshift=-1.8cm]current page.north west);
		\coordinate (bottom_right) at 
		    ([xshift=-1.8cm, yshift=1.8cm]current page.south east);
		\node[inner sep=0, anchor=north east] at (top_right) {\href{http://www.itba.edu.ar}{}};
		\draw[double, line width = 0.5pt] (top_left) rectangle (bottom_right);
	\end{tikzpicture}
	\par
	\vspace{-0.8cm}
	\noindent \textbf{CENTRO DE INVESTIGACIÓN Y DESARROLLO EN}\par
	\noindent \textbf{ELECTRONICA INDUSTRIAL (CIDEI)}\par
	\vspace{3cm}
	\begin{center}
		{\Huge \textbf{ARiCE Plattform}\par}
		{\huge \textbf{Getting Started Radiant}\par}
	\end{center}
	\vspace{1cm}
	\begin{center}
		
	\end{center}
	\vfill
	\noindent \textbf{AUTHORS:} Dr. Ing. Pablo \textsc{Cossutta} - Ing. Gonzalo \textsc{Castelli} \par
	\vfill
	\begin{center}
		\textbf{CIUDAD AUTÓNOMA DE BUENOS AIRES}\\
		\textbf{2018-2019}\par
	\end{center}
\end{titlepage}

\tableofcontents
\newpage

\section{Introduction}
This project is an open-source platform,shown on Fig. \ref{fig1},  based on a low cost and low consumption FPGA chip from \href{http://www.latticesemi.com}{Lattice Semiconductor}, aiming to be used in a wide range of signal processing and control applications, both for education and the industry.
%
\begin{figure}[h!]
	\centering
	\\
	%
	
	\caption{Board's view}
	\label{fig1}
\end{figure}

%\subsection{Project file sources}
%The following list shows the different file sources for this project:
%\begin{itemize}
%	\item Getting Started Guide and Documentation: \href{https://github.com/pcossutta/Lattice-FPGA/tree/master/Documents/Manuals}{GitHub manuals}
%	\item PCB and Schematics: \href{https://workspace.circuitmaker.com/Projects/Details/Gonzalo-Castelli/FPGA-ITBA}{Circuit Maker} and \href{https://github.com/pcossutta/Lattice-FPGA/tree/master/Altium}{GitHub Altium Project Files}
%	\item \href{https://github.com/pcossutta/Lattice-FPGA/tree/master/Examples/LedExample}{Example code} for the Lattice Radiant software.
%\end{itemize}

\section{Getting started}
Three main steps are necessary to use the board if you are starting from scratch. The first is to download the software and get a license, the second is to create a new project and include the code files needed and finally load the program to the onboard memory using a USB cable.

\subsection{Download the software}
Before using the board, it is necessary to set up the software to program the Lattice iCE40-UP5K FPGA chip. It is recommended to use \href{http://www.latticesemi.com/Products/DesignSoftwareAndIP/FPGAandLDS/Radiant}{Lattice Radiant software}, which supports iCE40 UltraPlus and offers all the best in class tools and features to develop edge applications effectively and efficiently. Free registration is required to download the software, and a license can be requested with no charge after providing the MAC address of the computer it will run on. 
This development also supports the \href{http://www.clifford.at/icestorm/}{iceStorm project}, Open Source toolchain by Clifford Wolf although its usage is not covered in this document.

\subsection{Create a new project}
After having installed and licensed the software, the next step is to create a new project in the Lattice Radiant Software and start writing HDL code. An example code that uses the onboard RGB LED is available for download at the GitHub repository of this project. After downloading the files, open the Lattice Radiant application and go to:
\begin{center}
	File $\rightarrow$ Open $\rightarrow$ Project...
\end{center}
Browse the folder you downloaded from GitHub and select the \texttt{getting\_started.rdf} file. You can now jump to the next section. To learn how to manually create a new project, click on the "New Project" icon in the start page, or by going to:
\begin{center}
	File $\rightarrow$ New $\rightarrow$ Project...
\end{center}
Follow the instructions of the wizard, and name the project "getting\_started". After clicking "Next", a new window will ask for source files. Click the "Add Source..." button and load the Verilog File you downloaded from the GitHub repository called "top.v". Check both boxes at the bottom of the window to generate all the necessary files in the project folder. The window should look like Fig. \ref{fig2}.
%
\begin{figure}[h!]
	\centering
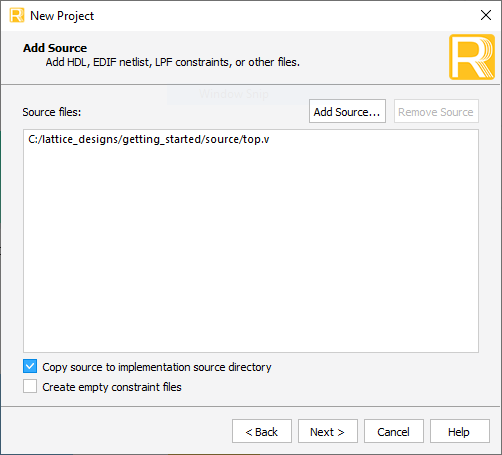
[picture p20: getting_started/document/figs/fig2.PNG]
	
	\caption{Adding source files to the new project}
	\label{fig2}
\end{figure}

Click "Next", and select the "iCE40UP5K" device. In the package pull-down menu, choose "SG48" and in the Part Number menu, pick "iCE40UP5K-SG48I". The window should look like Fig. \ref{fig3}.

\begin{figure}[h!]
	\centering
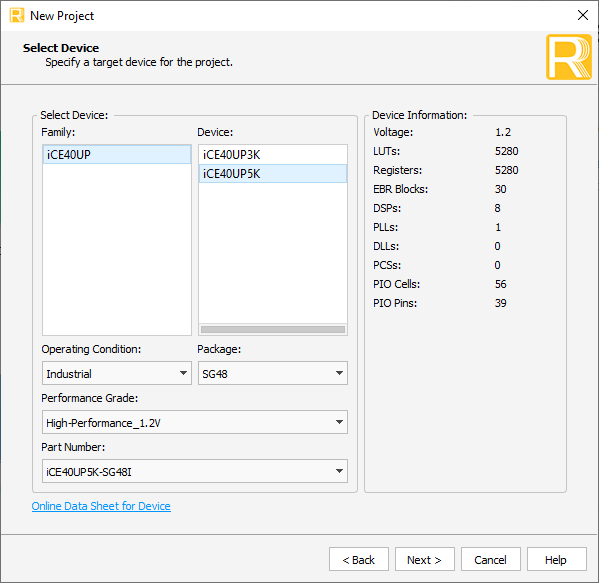
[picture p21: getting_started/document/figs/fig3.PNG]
	
	\caption{Selecting the device}
	\label{fig3}
\end{figure}

Then, click "Next" and "Finish" to conclude with the wizard. Now, replace the content of the \texttt{impl\_1.ldc}  and \texttt{impl\_1.pdc} files with the ones from our example in the GitHub repository. The project has now been set up, and the last step remaining is to load the code to the memory of the board.

\subsection{Board Programming}
Now that the project is fully set up, it is necessary to synthesize the design to create the export files. Click on the green play button on the upper-left corner to do so. The process should succeed, even though warnings will appear. Connect the FPGA board to the PC using the USB cable. To set up the device for programming, go to:
\begin{center}
	Tools $\rightarrow$ Programmer
\end{center}
In the Radiant Programmer window, the iCE40UP5K device should be displayed in the list. Select it by clicking on it, and go to:
\begin{center}
	Edit $\rightarrow$ Device Properties...
\end{center}
Configure the window so it looks like Fig. \ref{fig4}. Do not forget to include the programming file path, which was generated when doing the synthesis and which has a ".bin" extension. In our case, the file is \texttt{getting\_started\_impl1.bin}.

\begin{figure}[h!]
    \centering
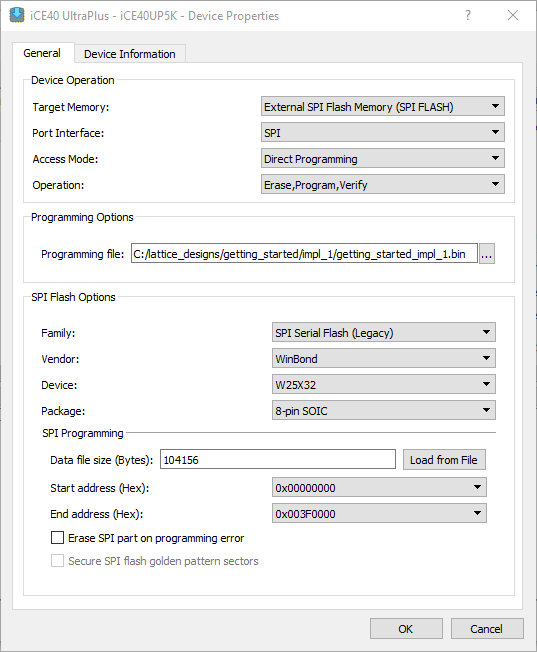
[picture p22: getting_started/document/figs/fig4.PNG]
    
    \caption{Programming properties}
    \label{fig4}
\end{figure}

Click "OK" to exit the window and to finally load the program to the board's memory go to:
\begin{center}
 Run $\rightarrow$ Program Device
\end{center}
If done successfully, the RGB LED of the FPGA board should be flashing in colors. 

\input{gs_common.tex}
\end{document}

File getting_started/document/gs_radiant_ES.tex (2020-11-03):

% !TEX encoding = UTF-8 Unicode
\documentclass[11pt, a4paper, oneside]{article}
\usepackage[onehalfspacing]{setspace}		% One half spacing
\usepackage{hyperref}					% Hyperlinks on pdf (Should be called before Geometry)
\usepackage[a4paper, 					% Page Layout
                     %showframe,				% This shows the frame
                     twoside, includehead,
                     footskip=7mm, headsep=6mm, headheight=4.8mm,
                     marginparsep=2mm, marginparwidth=22mm,
                     top=25mm, bottom=25mm, inner=30mm, outer=25mm]{geometry}
\usepackage{sansmathfonts}				% Sans Serif equations
\usepackage[T1]{fontenc}					% Output font encoding for international characters
\usepackage[utf8]{inputenc}				% Encoding of files: utf8
\renewcommand*\familydefault{\sfdefault} 		% Sans Serif as default font
%
\usepackage[spanish, es-tabla, es-nodecimaldot]{babel}
\addto\captionsspanish{\renewcommand{\contentsname}{Contenido}}
%
\usepackage[table]{xcolor}
\usepackage{graphicx}
\usepackage{pdfpages}
\usepackage{array}
\hypersetup{
    colorlinks=true,
    linkcolor=blue,
    filecolor=magenta,      
    urlcolor=blue,
}
\urlstyle{same}
\usepackage{tikz}
\RequirePackage{caption} 				% Caption customization
\captionsetup{justification=centerlast,font=small,labelfont=sc,margin=1cm}

\usepackage{array}
\newcommand{\PreserveBackslash}[1]{\let\temp=\\#1\let\\=\temp}
\newcolumntype{C}[1]{>{\PreserveBackslash\centering}p{#1}}
\newcolumntype{R}[1]{>{\PreserveBackslash\raggedleft}p{#1}}
\newcolumntype{L}[1]{>{\PreserveBackslash\raggedright}p{#1}}

\begin{document}
\begin{titlepage}
	\onehalfspacing
	\enlargethispage{0.65\baselineskip}
	\begin{tikzpicture}[remember picture, overlay]
		\coordinate (top_right) at 
		    ([xshift=-2.5cm, yshift=-2.5cm]current page.north east);
		\coordinate (top_left) at 
		    ([xshift=2.3cm, yshift=-1.8cm]current page.north west);
		\coordinate (bottom_right) at 
		    ([xshift=-1.8cm, yshift=1.8cm]current page.south east);
		\node[inner sep=0, anchor=north east] at (top_right) {\href{http://www.itba.edu.ar}{}};
		\draw[double, line width = 0.5pt] (top_left) rectangle (bottom_right);
	\end{tikzpicture}
	\par
	\vspace{-0.8cm}
	\noindent \textbf{CENTRO DE INVESTIGACIÓN Y DESARROLLO EN}\par
	\noindent \textbf{ELECTRONICA INDUSTRIAL (CIDEI)}\par
	\vspace{3cm}
	\begin{center}
		{\Huge \textbf{Plataforma ARiCE}\par}
		{\huge \textbf{Primeros Pasos Radiant}\par}
	\end{center}
	\vspace{1cm}
	\begin{center}
		
	\end{center}
	\vfill
	\noindent \textbf{AUTORES:} Dr. Ing. Pablo \textsc{Cossutta} - Ing. Gonzalo \textsc{Castelli} \par
	\vfill
	\begin{center}
		\textbf{CIUDAD AUTÓNOMA DE BUENOS AIRES}\\
		\textbf{2018-2019}\par
	\end{center}
\end{titlepage}

\tableofcontents
\newpage

\section{Introducción}
Este proyecto es una plataforma de código abierto, la cual se muestra en la Fig. \ref{fig1}, basado en una placa FPGA de bajo costo y bajo consumo de \href{http://www.latticesemi.com}{Lattice Semiconductor}. Tiene como objetivo ser utilizada en una amplia gama de aplicaciones de procesamiento de señales y control, tanto para la educación como para la industria.
%
\begin{figure}[h!]
	\centering
	\\
	%
	
	\caption{Vistas de la placa}
	\label{fig1}
\end{figure}

%\subsection{Project file sources}
%The following list shows the different file sources for this project:
%\begin{itemize}
%	\item Getting Started Guide and Documentation: \href{https://github.com/pcossutta/Lattice-FPGA/tree/master/Documents/Manuals}{GitHub manuals}
%	\item PCB and Schematics: \href{https://workspace.circuitmaker.com/Projects/Details/Gonzalo-Castelli/FPGA-ITBA}{Circuit Maker} and \href{https://github.com/pcossutta/Lattice-FPGA/tree/master/Altium}{GitHub Altium Project Files}
%	\item \href{https://github.com/pcossutta/Lattice-FPGA/tree/master/Examples/LedExample}{Example code} for the Lattice Radiant software.
%\end{itemize}

\section{Primeros pasos}
Hay tres pasos necesarios para utilizar la placa, empezando desde cero. Primero, descargar el software y obtener una licencia, luego crear un proyecto con los archivos y el codigo necesario. Finalmente, cargar el programa a la placa utilizando un cable USB.

\subsection{Descargar el software}

Antes de usar la placa, es necesario preparar el software con que programar el chip FPGA Lattice iCE40-UP5K. Se recomienda usar \href{http://www.latticesemi.com/Products/DesignSoftwareAndIP/FPGAandLDS/Radiant}{Lattice Radiant software}, que soporta la iCE40 UltraPlus que usaremos, y ofrece las mejores herramientas para desarrollar aplicaciones de manera eficiente y efectiva. Se requiere registrar una cuenta gratuita para descargar el software. Para solicitar una licencia gratuita para uso personal, se debe proveer la direccion MAC de la computadora donde se trabajará.

Esta placa tambien admite \href{http://www.clifford.at/icestorm/}{iceStorm project}, un toolchain Open Source desarrollado por Clifford Wolf, aunque su uso no esta cubierto en este documento.

\subsection{Crear un nuevo projecto}
Luego de instalar el software y registrado una licencia, el siguiento paso es crear un nuevo proyecto en el software Lattice Radiant y empezar a escribir código HDL. Un ejemplo de programa que utiliza el LED RGB de la placa esta disponible para descargar en el repositorio Github de este proyecto. Una vez descargados los archivos, abra Lattice Radiant y seleccione:

\begin{center}
	File $\rightarrow$ Open $\rightarrow$ Project...
\end{center}
Navegue a la carpeta descargada de Github y seleccione el archivo \texttt{getting\_started.rdf}. Puede ahora continuar a la proxima sección. Para aprender como crear manualmente un nuevo proyecto, haga click en "New Project" en la página de inicio, o seleccione:
\begin{center}
	File $\rightarrow$ New $\rightarrow$ Project...
\end{center}
Siga las instrucciones en la nueva ventana, y nombre al proyecto "getting\_started". Al continuar, una nueva pagina le pedirá los archivos fuente del proyecto. Haga click en "Add Source..." y carge el archivo Verilog descargado de Github llamado "top.v". Seleccione las opciones mostradas en la Figura 2 \ref{fig2} para generar todos los archivos necesarios en la carpeta de destino.
%
\begin{figure}[h!]
	\centering
	
	\caption{Agregando archivos fuente al proyecto}
	\label{fig2}
\end{figure}

En la siguiente ventana, seleccione el dispositivo "iCE40UP5K", con el Package "SG48". En el menu "Part Number", seleccione "iCE40UP5K-SG48I". La ventana deberia verse como en la Fig 3. \ref{fig3}

\begin{figure}[h!]
	\centering
	
	\caption{Seleccionando el dispositivo}
	\label{fig3}
\end{figure}

Continue hasta finalizar la ventana de creación del proyecto. Luego, reemplace el contenido de los archivos \texttt{impl\_1.ldc} y \texttt{impl\_1.ldc} con los encontrados en nuestro ejemplo en el repositorio Github. El proyecto está ahora preparado, y solo falta cargar el código a la memoria interna de la placa.

\subsection{Programación de la placa}

Ahora que el proyecto está listo, es necesario sintetizar el diseño para crear los archivos de exportación. Para hacerlo, haga click en el botón triangular verde en la esquina superior izquierda. El proceso debería ser excitoso, aunque pueden aparecer advertencias. Conecte la placa FPGA a su PC utilizando el cable USB. Para preparar la placa para ser programada, vaya a:
\begin{center}
	Tools $\rightarrow$ Programmer
\end{center}
En la ventana del Programador Radiant, el dispositivo iCE40UP5K debería aparecer en la lista. Seleccionelo, y vaya a:
\begin{center}
	Edit $\rightarrow$ Device Properties...
\end{center}
Configure la ventana como muestra la Fig. 4 \ref{fig4}. No olvide incluir la dirección del archivo programable, que se generó durante el proceso de Síntesis, y que tiene una extensión ".bin". En nuestro caso, el archivo es \texttt{getting\_started\_impl1.bin}.

\begin{figure}[h!]
    \centering
    
    \caption{Propiedades de la programación}
    \label{fig4}
\end{figure}

Haga click en "Ok" para salir de la ventana. Para finalmente cargar el programa a la memoria de la placa, vaya a:
\begin{center}
 Run $\rightarrow$ Program Device
\end{center}
Si todo salió bien, el LED RGB de la placa FPGA debera encenderse y cambiar de colores.
\input{gs_common_ES.tex}
\end{document}

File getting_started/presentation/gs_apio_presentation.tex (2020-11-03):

\documentclass{beamer}
\usetheme{Madrid}
\usecolortheme{default}

\definecolor{BlueITBA}{HTML}{00558c} 
\colorlet{beamer@blendedblue}{BlueITBA}
\setbeamertemplate{caption}{\scriptsize\insertcaption}
\setbeamertemplate{itemize items}[circle]
%\setbeamertemplate{itemize subitem}[triangle]
\setbeamertemplate{itemize subitem}{\raisebox{0.2em}{\scalebox{0.65}{$\blacktriangleright$}}}   % Second level

%\setbeamertemplate{enumerate items}[default]
\setbeamertemplate{section in toc}{\inserttocsectionnumber.~\inserttocsection}

\usepackage{sansmathfonts}				% Sans Serif equations
\usepackage[T1]{fontenc}					% Output font encoding for international characters
\usepackage[utf8]{inputenc}				% Encoding of files: utf8
\renewcommand*\familydefault{\sfdefault} 		% Sans Serif as default font
\usepackage{verbatim}
 
% Setup the language and its properties (choose only one)
\usepackage[spanish, es-tabla, es-nodecimaldot]{babel}
\addto\captionsspanish{\renewcommand{\contentsname}{Contenido}}

\usepackage{ulem}
\usepackage{graphicx}
\usepackage{tikz}						% Required for title page
\usepackage{hyperref}
\hypersetup{
    colorlinks=true,
    linkcolor=white,
    filecolor=magenta,      
    urlcolor=blue,
    citecolor=blue,    
}
\usepackage{listings}
\usepackage{adjustbox}
\definecolor{vgreen}{RGB}{104,180,104}
\definecolor{vblue}{RGB}{49,49,255}
\definecolor{vorange}{RGB}{255,143,102}
\lstset{
	basicstyle=\scriptsize,
	language=Verilog,
	tabsize=2,
	keywordstyle=\color{vblue},
	identifierstyle=\color{black},
	commentstyle=\color{vgreen},
	showstringspaces=false
}

\title[Primeros Pasos]{Primeros Pasos Apio}
\subtitle{}
\author{Dr. Ing. Pablo \textsc{Cossutta}}
\date{Octubre 2019}
\logo{} 
 
\begin{document}
\beamertemplatenavigationsymbolsempty % Disable Nav Bar
% Title and Intro
\maketitle
\logo{}

\begin{frame}{Tutorial}
¿Qué se va a hacer?
\begin{itemize}
	\item Instalar Python
	\begin{itemize}
		\item Seleccionar \texttt{pip}
	\end{itemize}
	\item Instalar Apio
	\item Crear un directorio de trabajo
	\item Cargar los archivos
	\item Synthesis, Map, Place \& Route, Bitstream
	\item Cargar el diseño
	\item Simular
\end{itemize}
¿Qué se necesita?
\begin{itemize}
	\item Archivo HDL (\texttt{gs\_apio.v})
	\item Constraints para implementación (\texttt{gs\_apio.pcf})	
	\item Testbench (\texttt{gs\_apio\_tb.pcf})	
\end{itemize}
\end{frame}
    
\begin{frame}[fragile]{gs\_apio.v - Definition and clock divider}
\begin{itemize}
	\item Similar al anterior solo modificar el nombre \texttt{rgb\_reg}
\end{itemize}
\begin{columns}
\column{0.5\textwidth}
\begin{center}\begin{adjustbox}{padding=2pt 0pt 0pt 0pt, cfbox=blue!50 1pt}\begin{lstlisting}
module top(
   output RGB0,
   output RGB1,
   output RGB2,
   input clk
);

localparam DIV_N = 22;

reg [DIV_N-1:0] div = 0;
always @(posedge clk) begin
	div <= div + 1'd1;
end

reg en;
always @(posedge clk) begin
	if (div==0) en <= 1'b1;
	else en <= 1'b0;
end
\end{lstlisting}\end{adjustbox}\end{center}
\column{0.5\textwidth}
\begin{center}\begin{adjustbox}{padding=2pt 0pt 0pt 0pt, cfbox=blue!50 1pt}\begin{lstlisting}
reg [2:0] rgb = 3'd0;
always @(posedge clk) begin
	if (en) begin
		case (rgb)
			3'b000:  rgb <= 3'b001;
			3'b001:  rgb <= 3'b010;
			3'b010:  rgb <= 3'b100;
			3'b100:  rgb <= 3'b000;
			default: rgb <= 3'b000;
		endcase
	end
end
\end{lstlisting}\end{adjustbox}\end{center}
\end{columns}
\end{frame}

\begin{frame}[fragile]{gs\_apio.v - SB\_RGBA Instantiation}
\begin{itemize}
	\item Cambia el nombre de la primitiva
\end{itemize}
\begin{center}\begin{adjustbox}{padding=2pt 0pt 0pt 0pt, cfbox=blue!50 1pt}\begin{lstlisting}
SB_RGBA_DRV RGBA_DRIVER (
	.CURREN(1'b1),
	.RGBLEDEN(1'b1),
	.RGB0PWM(rgb[0]),
	.RGB1PWM(rgb[1]),
	.RGB2PWM(rgb[2]),
	.RGB0(RGB0),
	.RGB1(RGB1),
	.RGB2(RGB2)
);

// Set parameters of RGBA_DRIVER
defparam RGBA_DRIVER.CURRENT_MODE = "0b0";
defparam RGBA_DRIVER.RGB0_CURRENT =  "0b000001"
defparam RGBA_DRIVER.RGB1_CURRENT =  "0b000001"
defparam RGBA_DRIVER.RGB2_CURRENT =  "0b000001"

endmodule
\end{lstlisting}\end{adjustbox}\end{center}
\end{frame}

\begin{frame}[fragile]{Restricciones (Constraints)}
Restricciones lógicas
\begin{itemize}
	\item No disponibles en Yosys
\end{itemize}
\vfill
Restricciones físicas
\begin{itemize}
	\item Necesarias para la implementación
	\item Hay que definir todo lo que sea E/S
\end{itemize}
\begin{block}{gs\_apio\_1.pcf}
\begin{lstlisting}
set_io clk 35
set_io RGB0 39
set_io RGB1 40
set_io RGB2 41
\end{lstlisting}
\end{block}
\end{frame}

\begin{frame}[fragile]{Testbench (analizar) \texttt{gs\_apio\_tb.v}}
\begin{center}\begin{adjustbox}{padding=2pt 0pt 0pt 0pt, cfbox=blue!50 1pt}\begin{lstlisting}
`default_nettype none
`timescale 1 ns / 100 ps

module led_cnt_tb();
parameter DURATION = 200;

reg clk;
always #1 clk = ~clk;

wire RGB0, RGB1, RGB2;
top top_inst (.RGB0(RGB0), .RGB1(RGB1), .RGB2(RGB2), .clk(clk));

initial begin
	$dumpfile("gs_apio_tb.vcd");
	$dumpvars(0, led_cnt_tb);
	#(DURATION) $display("End of simulation");
	$finish;
end

endmodule
\end{lstlisting}\end{adjustbox}\end{center}
\end{frame}

\begin{frame}[fragile]{Primitiva faltante}
\begin{itemize}
	\item Necesitamos la primitiva \texttt{SB\_RGBA\_DRV} para poder simular
\end{itemize}
\begin{center}\begin{adjustbox}{padding=2pt 0pt 0pt 0pt, cfbox=blue!50 1pt}\begin{lstlisting}
// Define primitive for simulation
module SB_RGBA_DRV #(
	parameter CURRENT_MODE=0,
	parameter RGB0_CURRENT=0,
	parameter RGB1_CURRENT=0,
	parameter RGB2_CURRENT=0
)(
	input CURREN,
	input RGBLEDEN,
	input RGB0PWM,
	input RGB1PWM,
	input RGB2PWM,
	output RGB0,
	output RGB1,
	output RGB2
);
assign RGB0 = (CURREN & RGBLEDEN) ? RGB0PWM : 1'b0;
assign RGB1 = (CURREN & RGBLEDEN) ? RGB1PWM : 1'b0;
assign RGB2 = (CURREN & RGBLEDEN) ? RGB2PWM : 1'b0;
endmodule
\end{lstlisting}\end{adjustbox}\end{center}
\end{frame}

\begin{frame}[fragile]{Testbench (corregido) \texttt{gs\_apio\_tb.v}}
\begin{center}\begin{adjustbox}{padding=2pt 0pt 0pt 0pt, cfbox=blue!50 1pt}\begin{lstlisting}
`default_nettype none
`timescale 1 ns / 100 ps

module top_tb();
parameter DURATION = 200;

reg clk = 0;
always #1 clk = ~clk;

wire RGB0, RGB1, RGB2;
top top_inst (.RGB0(RGB0), .RGB1(RGB1), .RGB2(RGB2), .clk(clk));

initial begin
	$dumpfile("gs_apio_tb.vcd");
	$dumpvars(0, top_tb);
	#(DURATION) $display("End of simulation");
	$finish;
end

endmodule
\end{lstlisting}\end{adjustbox}\end{center}
\end{frame}

\begin{frame}[fragile]{Trabajo en clase (Hands On)}
\begin{itemize}
	\item Registrar 2 veces la entrada
	\begin{itemize}	
		\item Prevenir metaestabilidad
	\end{itemize}
	\item Realizar el debouncing de una entrada correspondiente a un pulsador
	\begin{itemize}
		\item Considerando un debounce de N ciclos (ambas direcciones)
		\item Al detectar un pulso se enciende el led Rojo durante 500ms
	\end{itemize}
	\item Realizar un testbench completo
	\item Implementar y verificar experimentalmente
	\item Modificar para que no vuelva a encenderse si se mantiene el pulsador apretado
\end{itemize}
\end{frame}

\end{document}

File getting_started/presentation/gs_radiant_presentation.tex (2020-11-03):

\documentclass{beamer}
\usetheme{Madrid}
\usecolortheme{default}

\definecolor{BlueITBA}{HTML}{00558c} 
\colorlet{beamer@blendedblue}{BlueITBA}
\setbeamertemplate{caption}{\scriptsize\insertcaption}
\setbeamertemplate{itemize items}[circle]
%\setbeamertemplate{itemize subitem}[triangle]
\setbeamertemplate{itemize subitem}{\raisebox{0.2em}{\scalebox{0.65}{$\blacktriangleright$}}}   % Second level

%\setbeamertemplate{enumerate items}[default]
\setbeamertemplate{section in toc}{\inserttocsectionnumber.~\inserttocsection}

\usepackage{sansmathfonts}				% Sans Serif equations
\usepackage[T1]{fontenc}					% Output font encoding for international characters
\usepackage[utf8]{inputenc}				% Encoding of files: utf8
\renewcommand*\familydefault{\sfdefault} 		% Sans Serif as default font
\usepackage{verbatim}
 
% Setup the language and its properties (choose only one)
\usepackage[spanish, es-tabla, es-nodecimaldot]{babel}
\addto\captionsspanish{\renewcommand{\contentsname}{Contenido}}

\usepackage{ulem}
\usepackage{graphicx}
\usepackage{tikz}						% Required for title page
\usepackage{hyperref}
\hypersetup{
    colorlinks=true,
    linkcolor=white,
    filecolor=magenta,      
    urlcolor=blue,
    citecolor=blue,    
}
\usepackage{listings}

\title[Primeros Pasos]{Primeros Pasos Radiant}
\subtitle{}
\author{Dr. Ing. Pablo \textsc{Cossutta}}
%\institute[]{Dr. Ing. Miguel \textsc{Aguirre} - Ing. Analía \textsc{Douthat}}
\date{Octubre 2019}
\logo{} 
 
\begin{document}
\beamertemplatenavigationsymbolsempty % Disable Nav Bar
% Title and Intro
\maketitle
\logo{}

\begin{frame}{Tutorial}
¿Qué se va a hacer?
\begin{itemize}
	\item Instalar Radiant
	\begin{itemize}
		\item Requiere registrarse
		\item Requiere licencia
	\end{itemize}
	\item Crear un proyecto
	\item Cargar los archivos en el proyecto
	\item Synthesis, Map, Place \& Route, Bitstream
	\item Cargar el diseño
\end{itemize}
¿Qué se necesita?
\begin{itemize}
	\item Archivo HDL (top.v)
	\item Constraints para síntesis (impl\_1.ldc)
	\item Constraints para implementación (impl\_1.pdc)	
\end{itemize}
\end{frame}
    
\begin{frame}[fragile]{top.v - Definition and clock divider}
\begin{lstlisting}[language=Verilog]
module top(
   output RGB0,
   output RGB1,
   output RGB2,
   input clk
);

   reg [21:0] div = 22'd0;
   always @(posedge clk) div <= div + 1'd1;

   reg en;
   always @(posedge clk) begin
      if (div==22'd0) en <= 1'b1;
      else en <= 1'b0;
   end
\end{lstlisting}
\end{frame}

\begin{frame}[fragile]{top.v - Decoding}
\begin{lstlisting}[language=Verilog]
   reg [2:0] rgb_reg = 3'd0;
   always @(posedge clk) begin
      if (en) begin
         case (rgb_reg)
            3'b000:  rgb_reg <= 3'b001;
            3'b001:  rgb_reg <= 3'b010;
            3'b010:  rgb_reg <= 3'b100;
            3'b100:  rgb_reg <= 3'b000;
            default: rgb_reg <= 3'b000;
         endcase
      end
   end
\end{lstlisting}
\end{frame}

\begin{frame}[fragile]{top.v - RGB Instantiation}
\begin{lstlisting}[language=Verilog]
   RGB #(
     .CURRENT_MODE ("1"),
     .RGB0_CURRENT ("0b000001"),
     .RGB1_CURRENT ("0b000001"),
     .RGB2_CURRENT ("0b000001")
   ) RGB_INST (
     .CURREN   (1'b1),        // I
     .RGBLEDEN (1'b1),        // I
     .RGB0PWM  (rgb_reg[0]),  // I - Blue
     .RGB1PWM  (rgb_reg[1]),  // I - Green
     .RGB2PWM  (rgb_reg[2]),  // I - Red
     .RGB0     (RGB0),        // O
     .RGB1     (RGB1),	   // O
     .RGB2     (RGB2)         // O
   );
endmodule
\end{lstlisting}
\end{frame}

\begin{frame}[fragile]{Restricciones (Constraints)}
Restricciones lógicas
\begin{itemize}
	\item Generalmente necesarias para la síntesis
\end{itemize}
\begin{block}{impl\_1.ldc}
\begin{lstlisting}
create_clock -name {clk} -period 83.333 
-waveform \{0.000 41.666\} [get_ports clk]
\end{lstlisting}
\end{block}
\vfill
Restricciones físicas
\begin{itemize}
	\item Necesarias para la implementación
\end{itemize}
\begin{block}{impl\_1.pdc}
\begin{lstlisting}
ldc_set_location -site {35} [get_ports clk]
\end{lstlisting}
\end{block}
\end{frame}

\begin{frame}[fragile]{Trabajo en clase (Hands On)}
Utilizando los conocimientos adquiridos y la documentación correspondiente a la plataforma, implementar el siguiente diseño:
\begin{lstlisting}[language=Verilog]
module top(
   output j05,
   input j01, j02, j03, j04);

   assign j05 = j01 & j02 & j03 & j04;
endmodule
\end{lstlisting}
Cargar en la FPGA y analizar:
\begin{itemize}
	\item Analizar RTL
	\item Modificar lógica y analizar recursos
	\item Agregar una 5$^{ta}$ entrada adicional, repetir
\end{itemize}
\end{frame}

\end{document}

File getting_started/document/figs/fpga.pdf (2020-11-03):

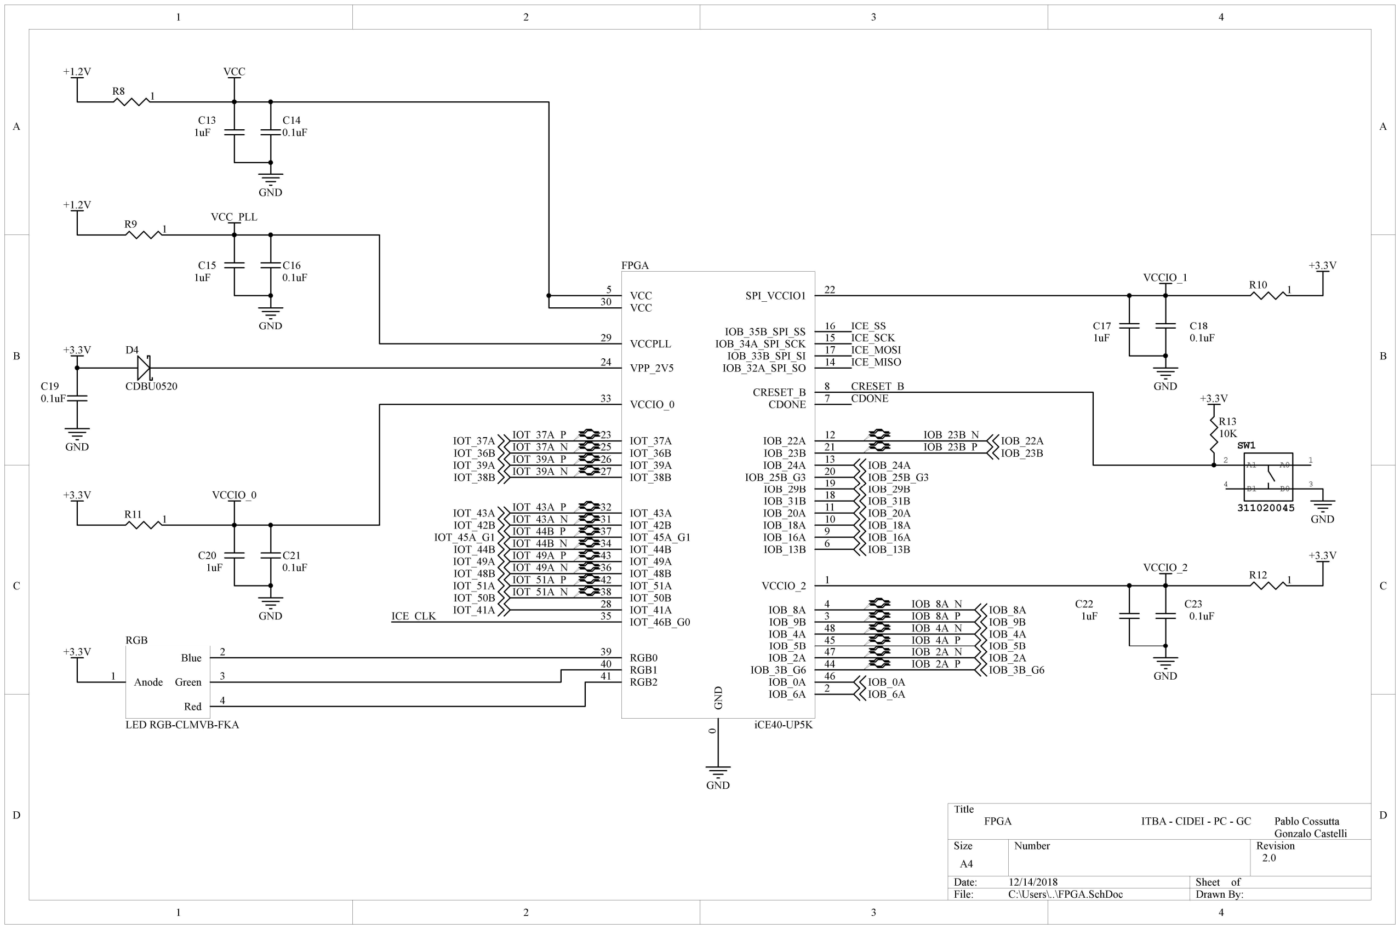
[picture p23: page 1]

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
Title

Size | Number | Revision
A4
Date: | 12/14/2018 | Sheet of
File: | C:\Users\..\FPGA.SchDoc | Drawn By:

0.1uF

C14
1uF

C13

GND

1

R8

+1.2V | VCC

1

R9

1uF

C15
0.1uF

C16

GND

VCC_PLL

+1.2V

0.1uF

C19

+3.3V

GND

0.1uF

C21
1uF

C20

VCCIO_0

1

R11

+3.3V

GND

GND

VCC 30 VCC 5

VPP_2V5 24

VCCPLL 29

VCCIO_0 33

IOT_37A 23
IOT_36B 25
IOT_39A 26
IOT_38B 27

IOT_43A 32
IOT_42B 31
IOT_45A_G1 37
IOT_44B 34
IOT_49A 43
IOT_48B 36
IOT_51A 42
IOT_50B 38
IOT_41A 28
IOT_46B_G0 35

RGB0 39
RGB1 40
RGB2 41 | GND

0

IOB_6A | 2
IOB_0A | 46 IOB_3B_G6 | 44 IOB_2A | 47 IOB_5B | 45 IOB_4A | 48 IOB_9B | 3
IOB_8A | | | | | | 4
VCCIO_2 | 1
IOB_13B | 6
IOB_16A | 9
IOB_18A | 10 IOB_20A | 11 IOB_31B | 18 IOB_29B | 19 IOB_25B_G3 | 20 IOB_24A | 13 IOB_23B | 21 IOB_22A | 12
CDONE | | | | | | | | 7
CRESET_B | 8
IOB_32A_SPI_SO | 14 IOB_33B_SPI_SI | 17 IOB_34A_SPI_SCK | 15 IOB_35B_SPI_SS | 16
SPI_VCCIO1 | | | | 22

FPGA

iCE40-UP5K

0.1uF

C18
1uF

C17

GND

VCCIO_1
1

R10

+3.3V

0.1uF

C23
1uF

C22

GND

VCCIO_2
1

R12

+3.3V

GND

CRESET_B
CDONE

10K

R13

+3.3V

ICE_SS
ICE_SCK
ICE_MOSI
ICE_MISO

Anode 1

Blue | 2
Green | 3
Red | 4

RGB

LED RGB-CLMVB-FKA

+3.3V

ICE_CLK

IOB_22A
IOB_23B
IOB_24A
IOB_25B_G3
IOB_29B
IOB_31B
IOB_20A
IOB_18A
IOB_16A
IOB_13B

IOB_8A
IOB_9B
IOB_4A
IOB_5B
IOB_2A
IOB_3B_G6
IOB_0A
IOB_6A

IOT_37A
IOT_36B
IOT_39A
IOT_38B

IOT_43A
IOT_42B
IOT_45A_G1
IOT_44B
IOT_49A
IOT_48B
IOT_51A
IOT_50B
IOT_41A

IOT_37A_P
IOT_37A_N
IOT_39A_P
IOT_39A_N

IOT_43A_P
IOT_43A_N
IOT_44B_P
IOT_44B_N
IOT_49A_P
IOT_49A_N
IOT_51A_P
IOT_51A_N

IOB_2A_P

IOB_2A_N

IOB_4A_P

IOB_4A_N

IOB_8A_P

IOB_8A_N

IOB_23B_N
IOB_23B_P

D4

CDBU0520

A0 1

A1 2

B0 3

B1 4

SW1

311020045

FPGA | ITBA - CIDEI - PC - GC

2.0

Gonzalo Castelli

Pablo Cossutta

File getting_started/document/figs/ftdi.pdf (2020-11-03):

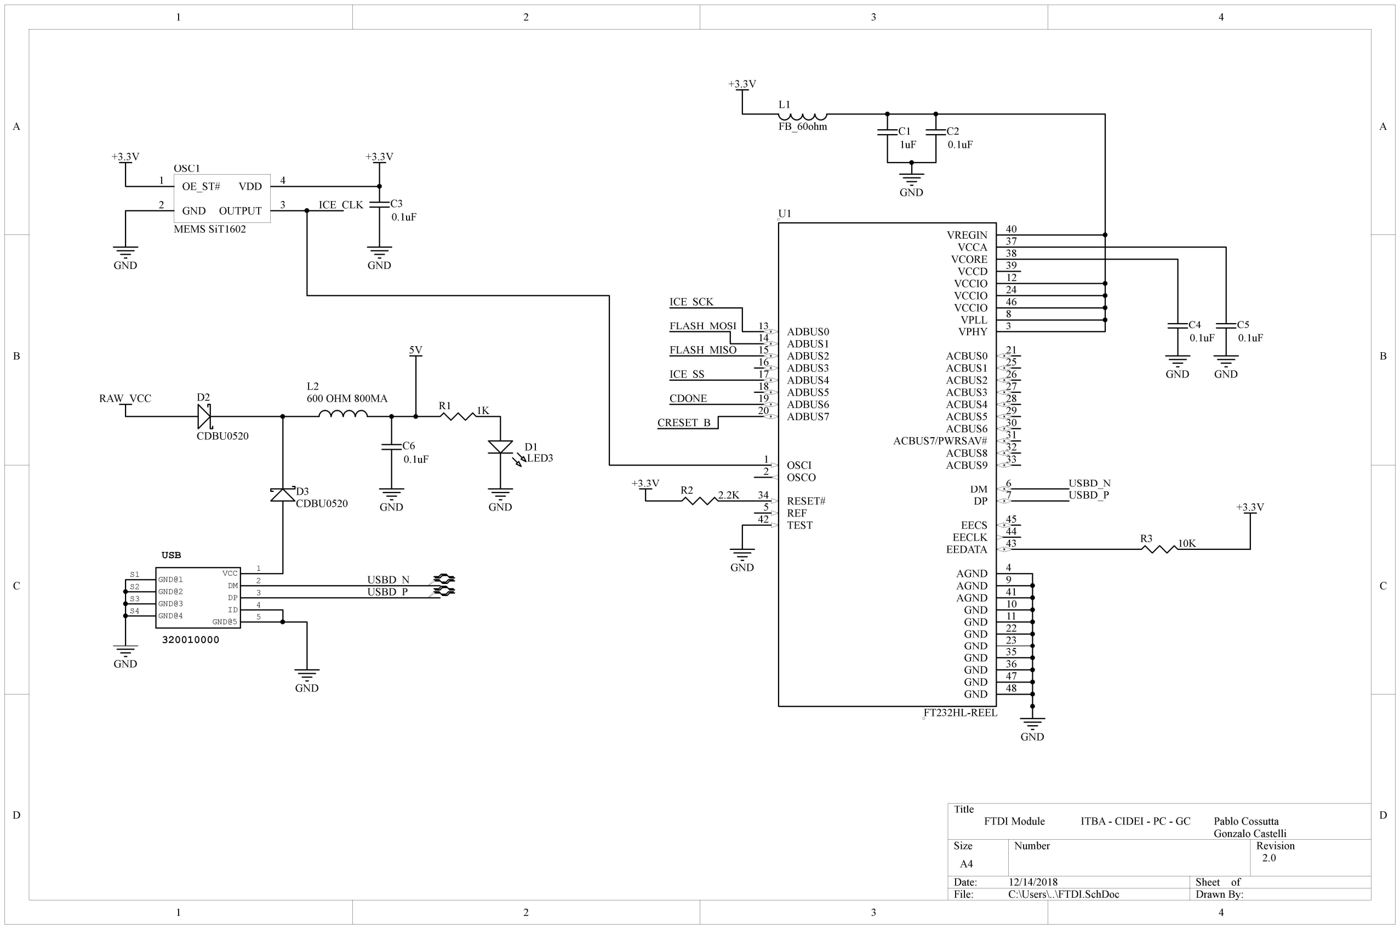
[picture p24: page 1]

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
Title

Size | Number | Revision
A4
Date: | 12/14/2018 | Sheet of
File: | C:\Users\..\FTDI.SchDoc | Drawn By:

OE_ST# 1

GND 2

VDD | 4
OUTPUT | 3

OSC1

MEMS SiT1602

GND

0.1uF

C3

GND

GND

L2
600 OHM 800MA

0.1uF

C6

1K R1

D1
LED3

GND

L1

FB_60ohm
0.1uF

C2
1uF

C1

GND

+3.3V

+3.3V

ICE_CLK

5V

D3
CDBU0520

USBD_N
USBD_P

2.2K R2 +3.3V

VCC | 1
DM | 2
DP | 3
ID | 4

GND@1 S1
GND@2 S2
GND@3 S3
GND@4 S4
GND@5 5

USB

320010000

GND

+3.3V

FTDI Module

2.0

Gonzalo Castelli

ITBA - CIDEI - PC - GC

ADBUS0 13
ADBUS1 14
ADBUS2 15
ADBUS3 16
ADBUS4 17
ADBUS5 18
ADBUS6 19
ADBUS7 20

OSCI 1
OSCO 2

RESET# 34
REF 5
TEST 42
VREGIN | 40
VCCA | 37
VCORE | 38
VCCD | 39
VCCIO | 12
VCCIO | 24
VCCIO | 46
VPLL | 8
VPHY | 3
ACBUS0 | 21
ACBUS1 | 25
ACBUS2 | 26
ACBUS3 | 27
ACBUS4 | 28
ACBUS5 | 29
ACBUS6 | 30
ACBUS7/PWRSAV# | 31
ACBUS8 | 32
ACBUS9 | 33
DM | 6
DP | 7
EECS | 45
EECLK | 44
EEDATA | 43
AGND | 4
AGND | 9
AGND | 41
GND | 10
GND | 11
GND | 22
GND | 23
GND | 35
GND | 36
GND | 47
GND | 48

U1

FT232HL-REEL

USBD_N
USBD_P

10K R3

GND

GND

+3.3V

ICE_SCK

FLASH_MOSI

FLASH_MISO

ICE_SS

CDONE

CRESET_B

0.1uF

C4
0.1uF

C5

GND GND

D2

CDBU0520

RAW_VCC

GND

Pablo Cossutta

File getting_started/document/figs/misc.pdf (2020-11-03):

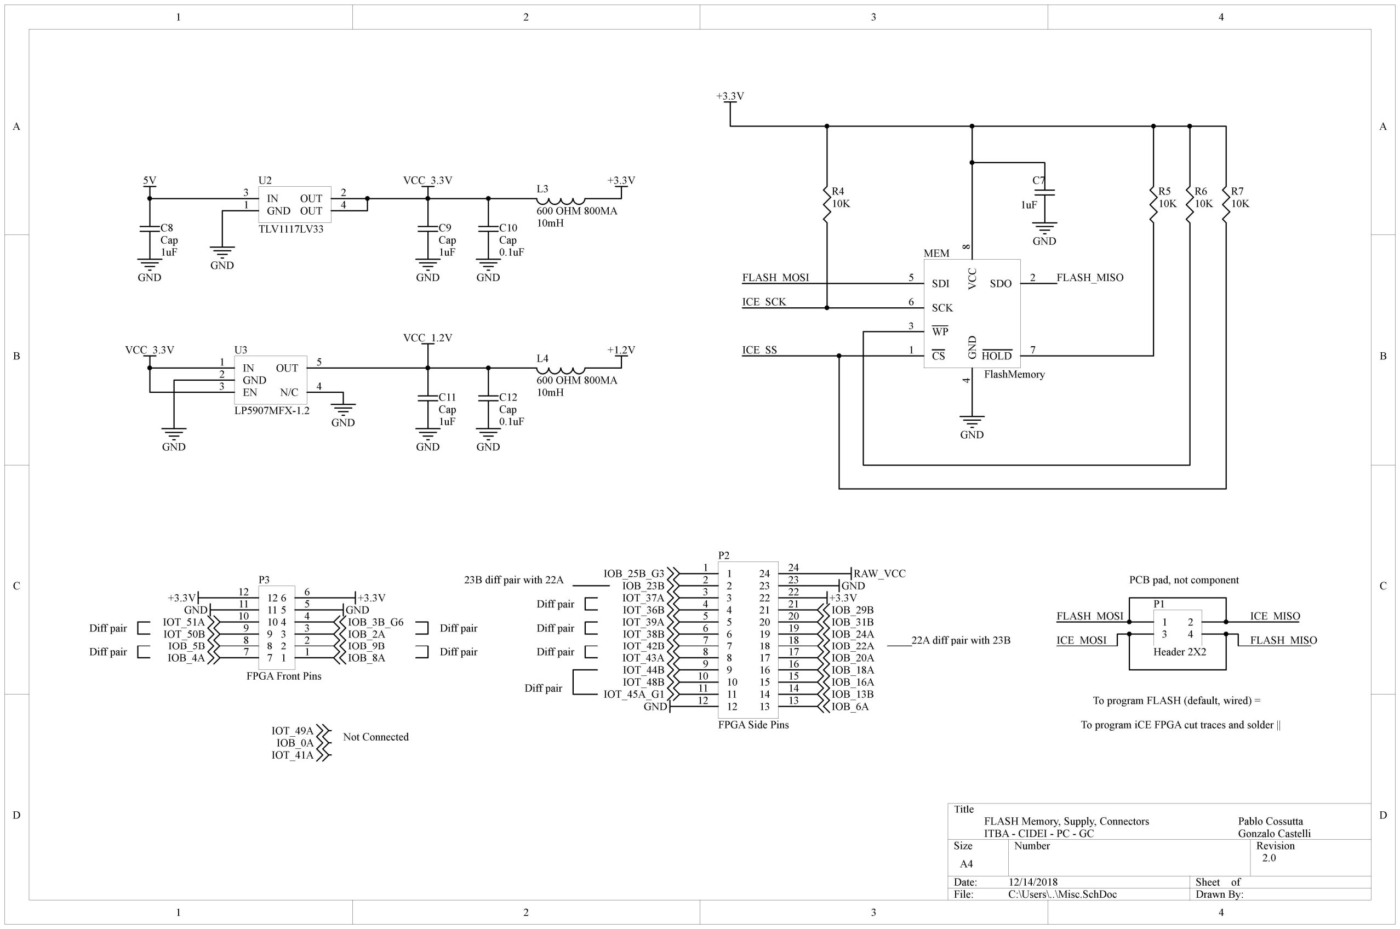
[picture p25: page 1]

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
Title

Size | Number | Revision
A4
Date: | 12/14/2018 | Sheet of
File: | C:\Users\..\Misc.SchDoc | Drawn By:

SDI 5

SCK 6

WP 3
CS 1 | GND

## 4 VCC

8

SDO | 2
HOLD | 7

MEM

FlashMemory

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
+3.3V

GND

GND

FLASH_MOSI | FLASH_MISO

ICE_SCK

ICE_SS

1 2
3 4

P1

Header 2X2

FLASH_MOSI

ICE_MOSI

ICE_MISO

FLASH_MISO

To program FLASH (default, wired) =

To program iCE FPGA cut traces and solder ||

ITBA - CIDEI - PC - GC

FLASH Memory, Supply, Connectors

PCB pad, not component

2.0

Gonzalo Castelli

Pablo Cossutta

IOB_3B_G6
IOB_2A
IOB_5B
IOB_4A

IOB_9B
IOB_8A

IOB_22A

IOB_23B

Diff pair

IOT_36B

IOT_37A

IOT_38B

IOT_39A

IOT_42B
IOT_43A
IOT_44B

IOT_45A_G1

IOT_48B

IOT_49A

IOT_50B

IOT_51A

Diff pair

Diff pair

Diff pair

Diff pair

Diff pair | Diff pair

Diff pair

IOB_25B_G3

IOB_29B
IOB_31B
IOB_24A

IOB_20A
IOB_18A
IOB_16A
IOB_13B
IOB_6A
IOB_0A | Not Connected
GND | GND
+3.3V | +3.3V | +3.3V

GND

GND

### 1 RAW_VCC 1

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
10 10
11 11
12 12 | 13 | 13 14 | 14 15 | 15 16 | 16 17 | 17 18 | 18 19 | 19 20 | 20 21 | 21 22 | 22 23 | 23 24 | 24

P2

FPGA Side Pins

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
10 10 | 11 11 | 12 12

P3

FPGA Front Pins

IOT_41A

22A diff pair with 23B

23B diff pair with 22A

GND 1

IN 3 | OUT | 2
| OUT | 4

U2

TLV1117LV33

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
VCC_3.3V

VCC_3.3V

GND

GND

VCC_1.2V

5V

10mH

L3

600 OHM 800MA

10mH

L4

600 OHM 800MA

0.1uF

C10
Cap

0.1uF

C12
Cap

GND

GND

+3.3V

+1.2V

1uF

C8
Cap

IN 1

EN 3

GND 2

OUT | 5
N/C | 4

U3

LP5907MFX-1.2
GND

GND

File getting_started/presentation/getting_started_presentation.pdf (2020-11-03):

## Primeros Pasos Radiant

Dr. Ing. Pablo Cossutta

Octubre 2019

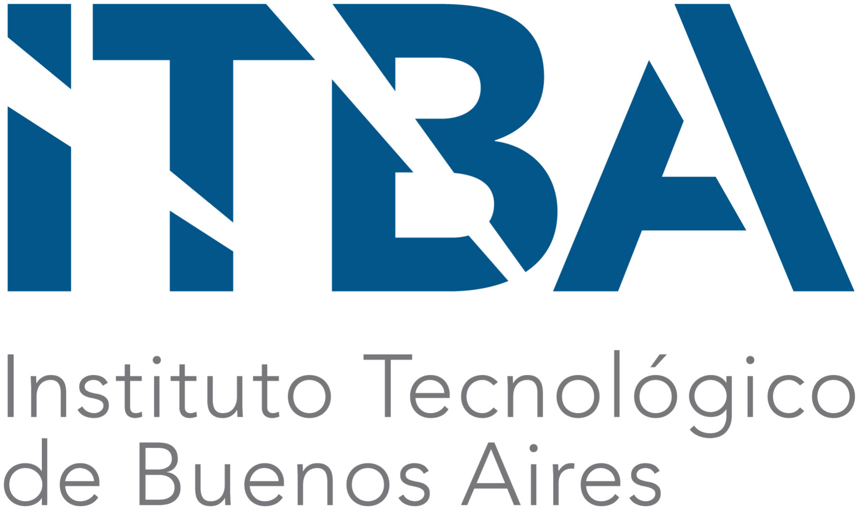
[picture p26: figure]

Dr. Ing. Pablo Cossutta | Primeros Pasos | Octubre 2019 | 1 / 1

## Tutorial

¿Qué se va a hacer?
- Instalar Radiant

I Requiere registrarse
I Requiere licencia
- Crear un proyecto
- Cargar los archivos en el proyecto
- Synthesis, Map, Place & Route, Bitstream
- Cargar el diseño

¿Qué se necesita?
- Archivo HDL (top.v)
- Constraints para síntesis (impl_1.ldc)
- Constraints para implementación (impl_1.pdc)
Dr. Ing. Pablo Cossutta | Primeros Pasos | Octubre 2019 | 2 / 1

## top.v - Definition and clock divider

module to p (
output RGB0,
output RGB1,
output RGB2,
inpu t c l k
) ;

reg [ 2 1 : 0 ] d i v = 22 ’ d0 ;
always @( posedge c l k ) d i v <= d i v + 1 ’ d1 ;

reg en ;
always @( posedge c l k ) begin
i f ( d i v ==22’d0 ) en <= 1 ’ b1 ; e l s e en <= 1 ’ b0 ;
end
Dr. Ing. Pablo Cossutta | Primeros Pasos | Octubre 2019 | 3 / 1

## top.v - Decoding

reg [ 2 : 0 ] rgb_ reg = 3 ’ d0 ; always @( posedge c l k ) begin i f ( en ) begin
case ( rgb_ reg )
3 ’ b000 : | rgb_ reg <= 3 ’ b001 ;
3 ’ b001 : | rgb_ reg <= 3 ’ b010 ;
3 ’ b010 : | rgb_ reg <= 3 ’ b100 ;
3 ’ b100 : | rgb_ reg <= 3 ’ b000 ;
d e f a ul t : rgb_ reg <= 3 ’ b000 ; endcase
end
end
Dr. Ing. Pablo Cossutta | Primeros Pasos | Octubre 2019 | 4 / 1

## top.v - RGB Instantiation

RGB #(
.CURRENT_MODE ( "1" ) ,
.RGB0_CURRENT ( "0 b000001 " ) , .RGB1_CURRENT ( "0 b000001 " ) , .RGB2_CURRENT ( "0 b000001 " )
) RGB_INST (
.CURREN | ( 1 ’ b1 ) , | // I
.RGBLEDEN ( 1 ’ b1 ) , | // I
.RGB0PWM | ( rgb_ reg [ 0 ] ) , | // I − Bl ue
.RGB1PWM | ( rgb_ reg [ 1 ] ) , | // I − G reen
.RGB2PWM | ( rgb_ reg [ 2 ] ) , | // I − Red
. RGB0 | (RGB0 ) , | // O
. RGB1 | (RGB1 ) , | // O
. RGB2 | (RGB2) | // O
) ;
endmodule
Dr. Ing. Pablo Cossutta | Primeros Pasos | Octubre 2019 | 5 / 1

## Restricciones (Constraints)

Restricciones lógicas
- Generalmente necesarias para la síntesis

impl_1.ldc

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

Restricciones físicas
- Necesarias para la implementación

impl_1.pdc

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

Dr. Ing. Pablo Cossutta | Primeros Pasos | Octubre 2019 | 6 / 1

## Trabajo en clase (Hands On)

Utilizando los conocimientos adquiridos y la documentación correspondiente a la plataforma, implementar el siguiente diseño:

module to p (
output j05 ,
inpu t j01 , j02 , j03 , j 0 4 ) ;

a s si g n j 0 5 = j 0 1 & j 0 2 & j 0 3 & j 0 4 ; endmodule

Cargar en la FPGA y analizar:
- Analizar RTL
- Modificar lógica y analizar recursos
- Agregar una 5ta entrada adicional, repetir
Dr. Ing. Pablo Cossutta | Primeros Pasos | Octubre 2019 | 7 / 1

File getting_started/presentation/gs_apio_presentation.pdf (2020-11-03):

# Primeros Pasos Apio

## Dr. Ing. Pablo Cossutta

## Octubre 2019


Dr. Ing. Pablo Cossutta | Primeros Pasos | Octubre 2019 | 1 / 9

# Tutorial

## ¿Qué se va a hacer? - Instalar Python

### I Seleccionar pip

## - Instalar Apio

## - Crear un directorio de trabajo

## - Cargar los archivos

## - Synthesis, Map, Place & Route, Bitstream

## - Cargar el diseño

## - Simular

## ¿Qué se necesita? - Archivo HDL (gs_apio.v)

## - Constraints para implementación (gs_apio.pcf)

### - Testbench (gs_apio_tb.pcf)

Dr. Ing. Pablo Cossutta | Primeros Pasos | Octubre 2019 | 2 / 9

# gs_apio.v - Definition and clock divider

## - Similar al anterior solo modificar el nombre rgb_reg

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

l o c a l p a r a m DIV_N = 2 2;

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

r e g [ 2 : 0 ] r g b = 3 ’ d0 ;
a l w a y s @( p o s e d g e c l k ) b e g i n
i f ( en ) b e g i n
c a s e ( r g b )
3 ’ b000 : | r g b <= 3 ’ b001 ;
3 ’ b001 : | r g b <= 3 ’ b010 ;
3 ’ b010 : | r g b <= 3 ’ b100 ;
3 ’ b100 : | r g b <= 3 ’ b000 ;
d e f a u l t : r g b <= 3 ’ b000 ; e n d c a s e
end
end
Dr. Ing. Pablo Cossutta | Primeros Pasos | Octubre 2019 | 3 / 9

# gs_apio.v - SB_RGBA Instantiation

## - Cambia el nombre de la primitiva

SB_RGBA_DRV RGBA_DRIVER (
.CURREN( 1 ’ b1 ) ,
.RGBLEDEN( 1 ’ b1 ) ,
.RGB0PWM( r g b [ 0 ] ) ,
.RGB1PWM( r g b [ 1 ] ) ,
.RGB2PWM( r g b [ 2 ] ) ,
.RGB0(RGB0) ,
.RGB1(RGB1) ,
.RGB2(RGB2)
) ;

// Se t p a r am e t e r s o f RGBA_DRIVER
de fp a r am RGBA_DRIVER.CURRENT_MODE = "0 b0 " ;
de fp a r am RGBA_DRIVER.RGB0_CURRENT = | "0 b000001 "
de fp a r am RGBA_DRIVER.RGB1_CURRENT = | "0 b000001 "
de fp a r am RGBA_DRIVER.RGB2_CURRENT = | "0 b000001 "

endmodule

Dr. Ing. Pablo Cossutta | Primeros Pasos | Octubre 2019 | 4 / 9

# Restricciones (Constraints)

## Restricciones lógicas - No disponibles en Yosys

## Restricciones físicas - Necesarias para la implementación

## - Hay que definir todo lo que sea E/S

## gs_apio_1.pcf

s e t_ i o c l k 35
s e t_ i o RGB0 39
s e t_ i o RGB1 40
s e t_ i o RGB2 41
Dr. Ing. Pablo Cossutta | Primeros Pasos | Octubre 2019 | 5 / 9

# Testbench (analizar) gs_apio_tb.v

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

module led_cn t_ tb ( ) ;
p a r am e t e r DURATION = 2 0 0;

r e g c l k ;
a l w a y s #1 c l k = ~c l k ;

w i r e RGB0 , RGB1 , RGB2 ;
t o p t o p_ i n s t ( .RGB0(RGB0) , .RGB1(RGB1) , .RGB2(RGB2) , . c l k ( c l k ) ) ;

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

end

endmodule

Dr. Ing. Pablo Cossutta | Primeros Pasos | Octubre 2019 | 6 / 9

# Primitiva faltante

## - Necesitamos la primitiva SB_RGBA_DRV para poder simular

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

# Testbench (corregido) gs_apio_tb.v

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

module top_tb ( ) ;
p a r am e t e r DURATION = 2 0 0;

r e g c l k = 0 ;
a l w a y s #1 c l k = ~c l k ;

w i r e RGB0 , RGB1 , RGB2 ;
t o p t o p_ i n s t ( .RGB0(RGB0) , .RGB1(RGB1) , .RGB2(RGB2) , . c l k ( c l k ) ) ;

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

end

endmodule

Dr. Ing. Pablo Cossutta | Primeros Pasos | Octubre 2019 | 8 / 9

# Trabajo en clase (Hands On)

## - Registrar 2 veces la entrada

### I Prevenir metaestabilidad

## - Realizar el debouncing de una entrada correspondiente a un pulsador

### I Considerando un debounce de N ciclos (ambas direcciones) I Al detectar un pulso se enciende el led Rojo durante 500ms

## - Realizar un testbench completo

## - Implementar y verificar experimentalmente

## - Modificar para que no vuelva a encenderse si se mantiene el pulsador apretado

Dr. Ing. Pablo Cossutta | Primeros Pasos | Octubre 2019 | 9 / 9
